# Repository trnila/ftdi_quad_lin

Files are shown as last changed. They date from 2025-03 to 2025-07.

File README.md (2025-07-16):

# FTDI Quad LIN

FTDI Quad-LIN is an FTDI-based board that enables communication with up to 4 LIN channels.

- 4x LIN master channels
- USB-C connector
- channel LED indication of power presence and communication activity
- power jack to power selected transceiver and its network

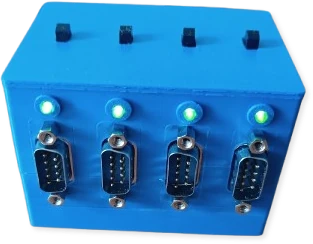
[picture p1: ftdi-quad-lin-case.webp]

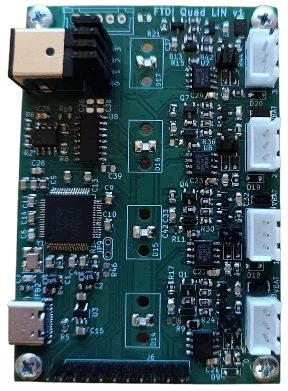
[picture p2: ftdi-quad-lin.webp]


## Getting started
Install dkms driver for sllin module:
```
$ ./install_driver.sh
```

Then run following commands to:
- write given serial number into the device
- install a udev rule to start `ldattach@.service` on USB plug-in
- copy `sllin.network` file to automatically bringup `slcan` interface up

```
$ sudo apt install ftdi-eeprom
$ ./setup.sh some_serial_number
```

## Tests

Connect all channels to 2x PCAN-USB Pro, then install peak driver:
```sh
$ wget https://www.peak-system.com/quick/PLIN-Linux-Driver -O plin_linux_driver.tar.gz
$ tar -xf plin_linux_driver.tar.gz
$ cd peak-lin-driver-1.4.0
$ make
$ sudo make install
```

Then test all channels as masters by sending frames to the connected PCAN-USB device:
```
$ uv run pytest
```

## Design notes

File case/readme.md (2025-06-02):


# Case
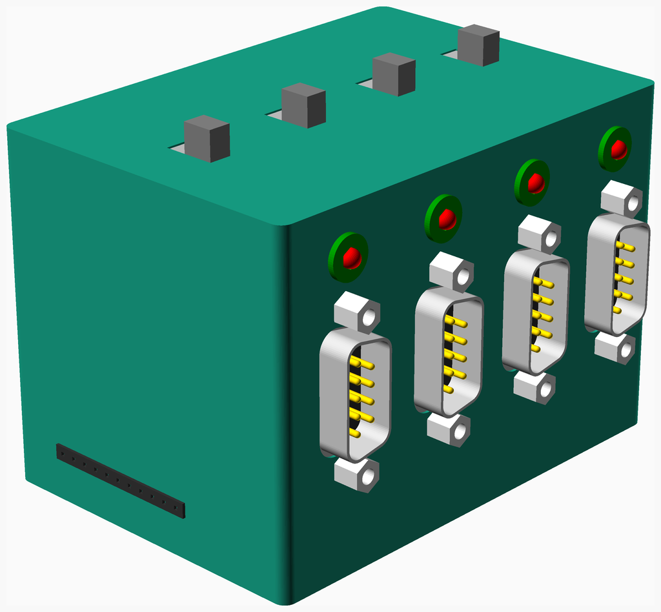
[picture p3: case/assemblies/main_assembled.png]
Main Assembly


<span></span>

---
## Table of Contents
1. [Parts list](#Parts_list)
1. [Ftdi Quad Lin Box Base Assembly](#ftdi_quad_lin_box_base_assembly)
1. [Led Activity Assembly](#led_activity_assembly)
1. [Ftdi Quad Lin Box Assembly](#ftdi_quad_lin_box_assembly)
1. [Main Assembly](#main_assembly)

<span></span>
[Top](#TOP)

---

## Parts list
| <span style="writing-mode: vertical-rl; text-orientation: mixed;">Ftdi&nbsp;Quad&nbsp;Lin&nbsp;Box&nbsp;Base</span> | <span style="writing-mode: vertical-rl; text-orientation: mixed;">4 x Led&nbsp;Activity</span> | <span style="writing-mode: vertical-rl; text-orientation: mixed;">Ftdi&nbsp;Quad&nbsp;Lin&nbsp;Box</span> | <span style="writing-mode: vertical-rl; text-orientation: mixed;">Main</span> | <span style="writing-mode: vertical-rl; text-orientation: mixed;">TOTALS</span> |  |
|---:|---:|---:|---:|---:|:---|
|  |  |  |  | | **Vitamins** |
| &nbsp;&nbsp;.&nbsp; | &nbsp;&nbsp;.&nbsp; | &nbsp;&nbsp;4&nbsp; | &nbsp;&nbsp;.&nbsp; |  &nbsp;&nbsp;4&nbsp; | &nbsp;&nbsp; D-type 9 way  plug |
| &nbsp;&nbsp;.&nbsp; | &nbsp;&nbsp;.&nbsp; | &nbsp;&nbsp;8&nbsp; | &nbsp;&nbsp;.&nbsp; |  &nbsp;&nbsp;8&nbsp; | &nbsp;&nbsp; D-type connector pillar |
| &nbsp;&nbsp;.&nbsp; | &nbsp;&nbsp;.&nbsp; | &nbsp;&nbsp;.&nbsp; | &nbsp;&nbsp;4&nbsp; |  &nbsp;&nbsp;4&nbsp; | &nbsp;&nbsp; Heatfit insert M3 x 3mm |
| &nbsp;&nbsp;4&nbsp; | &nbsp;&nbsp;.&nbsp; | &nbsp;&nbsp;.&nbsp; | &nbsp;&nbsp;.&nbsp; |  &nbsp;&nbsp;4&nbsp; | &nbsp;&nbsp; JST XH connector 3 way |
| &nbsp;&nbsp;1&nbsp; | &nbsp;&nbsp;.&nbsp; | &nbsp;&nbsp;.&nbsp; | &nbsp;&nbsp;.&nbsp; |  &nbsp;&nbsp;1&nbsp; | &nbsp;&nbsp; JST XH connector 5 way |
| &nbsp;&nbsp;.&nbsp; | &nbsp;&nbsp;4&nbsp; | &nbsp;&nbsp;.&nbsp; | &nbsp;&nbsp;.&nbsp; |  &nbsp;&nbsp;4&nbsp; | &nbsp;&nbsp; LED 3 mm red |
| &nbsp;&nbsp;.&nbsp; | &nbsp;&nbsp;.&nbsp; | &nbsp;&nbsp;8&nbsp; | &nbsp;&nbsp;.&nbsp; |  &nbsp;&nbsp;8&nbsp; | &nbsp;&nbsp; Nut M2 x 1.6mm  |
| &nbsp;&nbsp;1&nbsp; | &nbsp;&nbsp;.&nbsp; | &nbsp;&nbsp;.&nbsp; | &nbsp;&nbsp;.&nbsp; |  &nbsp;&nbsp;1&nbsp; | &nbsp;&nbsp; Pin socket 11 x 1 right_angle |
| &nbsp;&nbsp;.&nbsp; | &nbsp;&nbsp;.&nbsp; | &nbsp;&nbsp;.&nbsp; | &nbsp;&nbsp;4&nbsp; |  &nbsp;&nbsp;4&nbsp; | &nbsp;&nbsp; Screw M3 pan x  6mm |
| &nbsp;&nbsp;.&nbsp; | &nbsp;&nbsp;.&nbsp; | &nbsp;&nbsp;4&nbsp; | &nbsp;&nbsp;.&nbsp; |  &nbsp;&nbsp;4&nbsp; | &nbsp;&nbsp; SlideSwitch |
| &nbsp;&nbsp;.&nbsp; | &nbsp;&nbsp;.&nbsp; | &nbsp;&nbsp;.&nbsp; | &nbsp;&nbsp;4&nbsp; |  &nbsp;&nbsp;4&nbsp; | &nbsp;&nbsp; Washer  M3 x 7mm x 0.5mm |
| &nbsp;&nbsp;1&nbsp; | &nbsp;&nbsp;.&nbsp; | &nbsp;&nbsp;.&nbsp; | &nbsp;&nbsp;.&nbsp; |  &nbsp;&nbsp;1&nbsp; | &nbsp;&nbsp; ftdi quad lin |
| &nbsp;&nbsp;7&nbsp; | &nbsp;&nbsp;4&nbsp; | &nbsp;&nbsp;24&nbsp; | &nbsp;&nbsp;12&nbsp; | &nbsp;&nbsp;47&nbsp; | &nbsp;&nbsp;Total vitamins count |
|  |  |  |  | | **3D printed parts** |
| &nbsp;&nbsp;.&nbsp; | &nbsp;&nbsp;4&nbsp; | &nbsp;&nbsp;.&nbsp; | &nbsp;&nbsp;.&nbsp; |  &nbsp;&nbsp;4&nbsp; | &nbsp;&nbsp;LED3mm_bezel.stl |
| &nbsp;&nbsp;.&nbsp; | &nbsp;&nbsp;.&nbsp; | &nbsp;&nbsp;4&nbsp; | &nbsp;&nbsp;.&nbsp; |  &nbsp;&nbsp;4&nbsp; | &nbsp;&nbsp;LED3mm_bezel_retainer.stl |
| &nbsp;&nbsp;.&nbsp; | &nbsp;&nbsp;.&nbsp; | &nbsp;&nbsp;1&nbsp; | &nbsp;&nbsp;.&nbsp; |  &nbsp;&nbsp;1&nbsp; | &nbsp;&nbsp;ftdi_quad_lin_box.stl |
| &nbsp;&nbsp;1&nbsp; | &nbsp;&nbsp;.&nbsp; | &nbsp;&nbsp;.&nbsp; | &nbsp;&nbsp;.&nbsp; |  &nbsp;&nbsp;1&nbsp; | &nbsp;&nbsp;ftdi_quad_lin_box_base.stl |
| &nbsp;&nbsp;1&nbsp; | &nbsp;&nbsp;4&nbsp; | &nbsp;&nbsp;5&nbsp; | &nbsp;&nbsp;.&nbsp; | &nbsp;&nbsp;10&nbsp; | &nbsp;&nbsp;Total 3D printed parts count |

<span></span>
[Top](#TOP)

---

## Ftdi Quad Lin Box Base Assembly
### Vitamins
|Qty|Description|
|---:|:---|
|4| JST XH connector 3 way|
|1| JST XH connector 5 way|
|1| Pin socket 11 x 1 right_angle|
|1| ftdi quad lin|

### 3D Printed parts

| 1 x ftdi_quad_lin_box_base.stl |
|---|
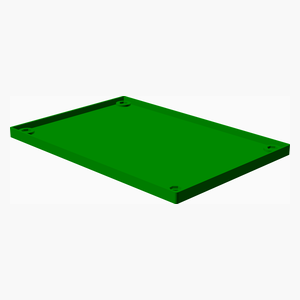
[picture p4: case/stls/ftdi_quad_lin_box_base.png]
ftdi_quad_lin_box_base.stl
|  

### Assembly instructions
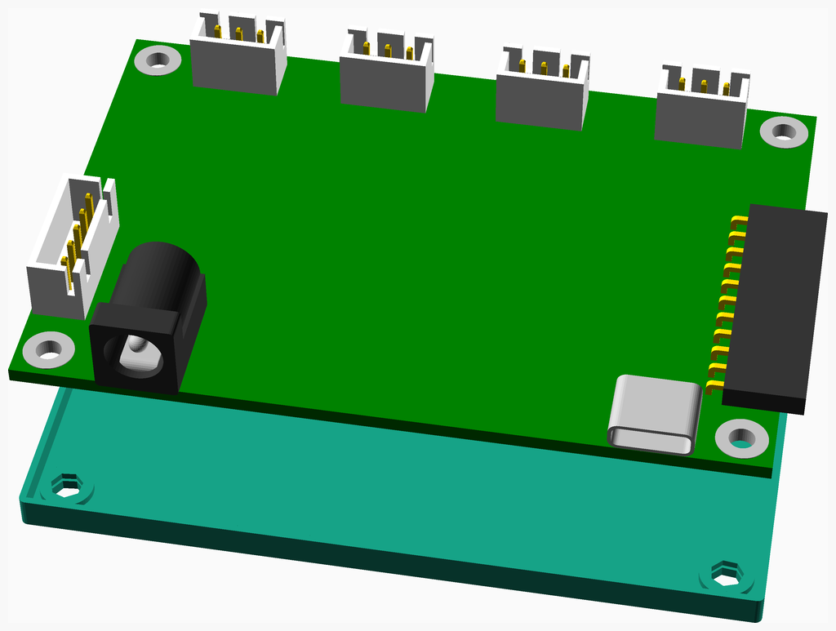
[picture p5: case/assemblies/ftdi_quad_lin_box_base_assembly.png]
ftdi_quad_lin_box_base_assembly


Place FTDI Quad LIN PCB into base part.

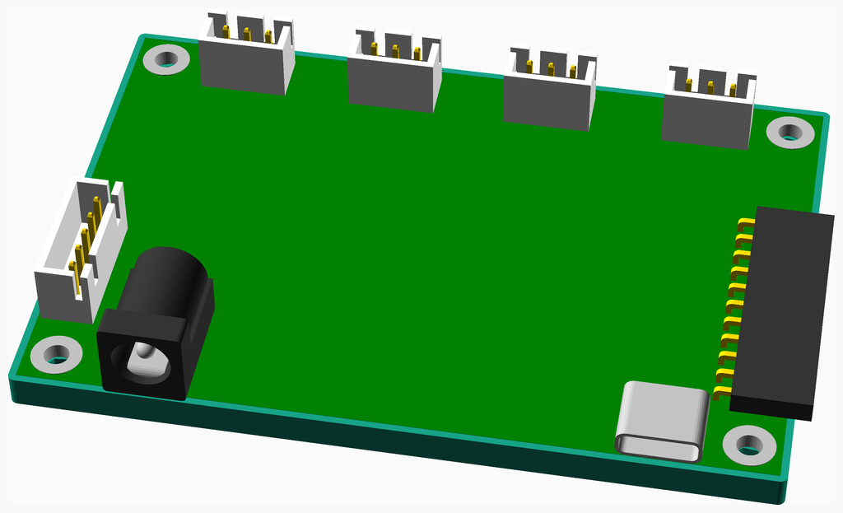
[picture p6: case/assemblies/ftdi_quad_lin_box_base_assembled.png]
ftdi_quad_lin_box_base_assembled


<span></span>
[Top](#TOP)

---

## 4 x Led Activity Assembly
### Vitamins
|Qty|Description|
|---:|:---|
|4| LED 3 mm red|

### 3D Printed parts

| 4 x LED3mm_bezel.stl |
|---|
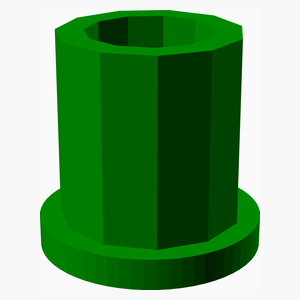
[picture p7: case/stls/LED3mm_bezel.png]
LED3mm_bezel.stl
|  

### Assembly instructions
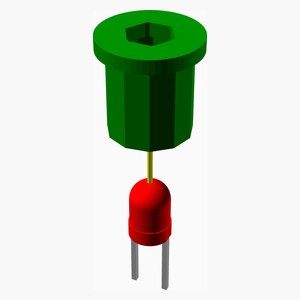
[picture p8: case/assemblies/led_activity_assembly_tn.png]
led_activity_assembly


1. Solder wire from J7 pin 5 to 3th LED anode (+)
1. Chain and solder wire to all other anodes (+)
1. solder 3th LED cathode (-) to J7 pin 4
1. solder 2th LED cathode (-) to J7 pin 3
1. solder 1th LED cathode (-) to J7 pin 2
1. solder 0th LED cathode (-) to J7 pin 1
1. Insert LEDs into the bezels

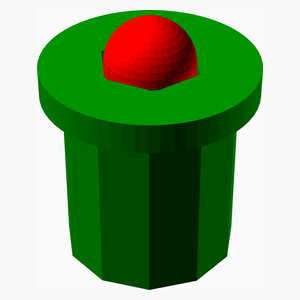
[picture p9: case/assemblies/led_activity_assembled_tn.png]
led_activity_assembled


<span></span>
[Top](#TOP)

---

## Ftdi Quad Lin Box Assembly
### Vitamins
|Qty|Description|
|---:|:---|
|4| D-type 9 way  plug|
|8| D-type connector pillar|
|8| Nut M2 x 1.6mm |
|4| SlideSwitch|

### 3D Printed parts

| 4 x LED3mm_bezel_retainer.stl | 1 x ftdi_quad_lin_box.stl |
|---|---|
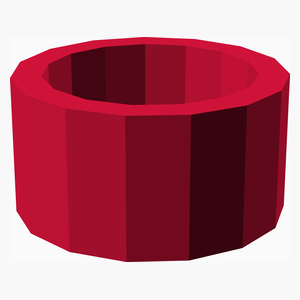
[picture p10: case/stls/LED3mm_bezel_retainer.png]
LED3mm_bezel_retainer.stl
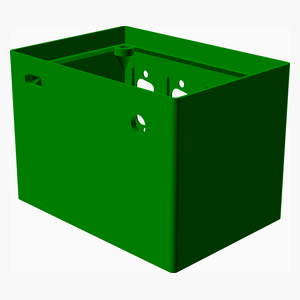
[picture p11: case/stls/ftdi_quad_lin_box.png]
ftdi_quad_lin_box.stl
|  |  

### Sub-assemblies

| 4 x led_activity_assembly |
|---|
| led_activity_assembled 

### Assembly instructions
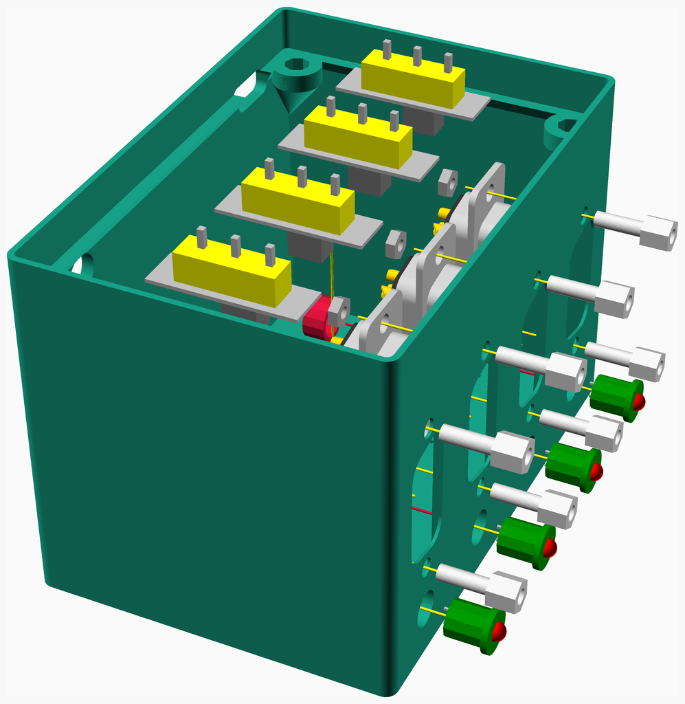
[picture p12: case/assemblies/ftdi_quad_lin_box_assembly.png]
ftdi_quad_lin_box_assembly


1. Insert 4x LED with bezel into hole and screw with retainer
2. Insert 4x slide switches and glue them inside
3. insert 4x DCONN9 connectors and secure them with pillar and nuts

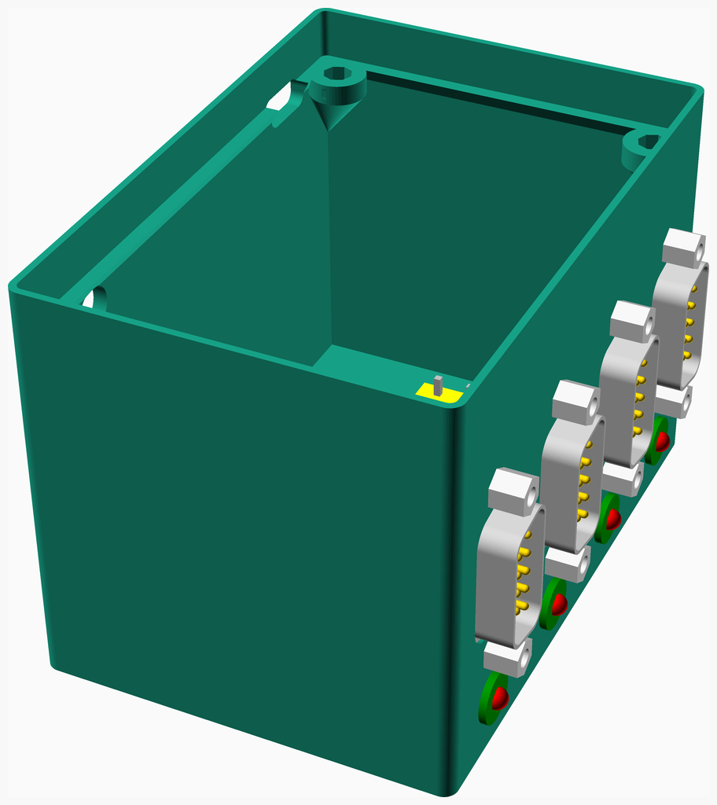
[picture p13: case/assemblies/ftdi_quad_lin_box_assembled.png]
ftdi_quad_lin_box_assembled


<span></span>
[Top](#TOP)

---

## Main Assembly
### Vitamins
|Qty|Description|
|---:|:---|
|4| Heatfit insert M3 x 3mm|
|4| Screw M3 pan x  6mm|
|4| Washer  M3 x 7mm x 0.5mm|

### Sub-assemblies

| 1 x ftdi_quad_lin_box_assembly | 1 x ftdi_quad_lin_box_base_assembly |
|---|---|
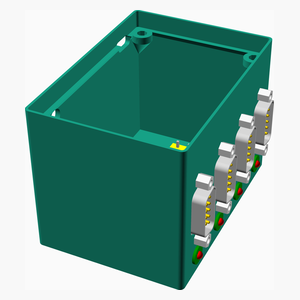
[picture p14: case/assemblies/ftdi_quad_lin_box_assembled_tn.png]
ftdi_quad_lin_box_assembled
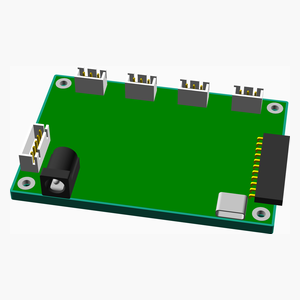
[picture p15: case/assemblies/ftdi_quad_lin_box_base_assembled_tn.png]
ftdi_quad_lin_box_base_assembled
|  |  

### Assembly instructions
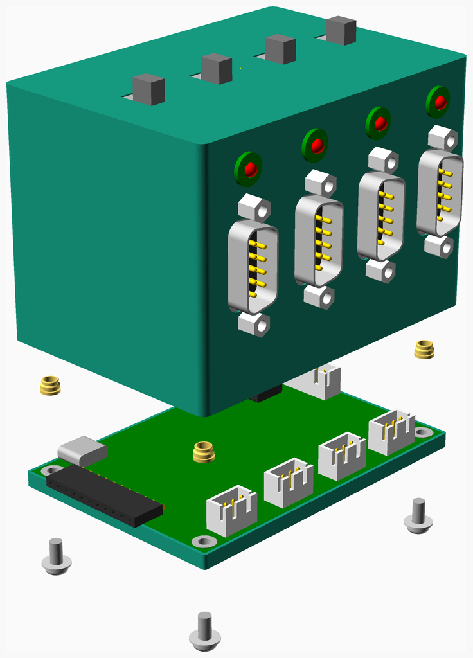
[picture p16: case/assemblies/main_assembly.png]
main_assembly


1. Place 4x heated inserts
1. Connect LEDs wire into J7
1. Connect LIN 0 power switch to JP5
1. Connect LIN 1 power switch to JP6 
1. Connect LIN 2 power switch to JP7 
1. Connect LIN 3 power switch to JP8 
1. Connect LIN 1 CONN9 to J2
1. Connect LIN 2 CONN9 to J3
1. Connect LIN 3 CONN9 to J4
1. Connect LIN 4 CONN9 to J5
1. Screw base into the box with 4x M3 screws
1. Screw the base into the box

main_assembled

<span></span>
[Top](#TOP)

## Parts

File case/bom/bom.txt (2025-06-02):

Vitamins:
    F      
    t      
    d      
    i      
           
 F  q      
 t  u      
 d  a      
 i  d      
           
 q  l  L   
 u  i  e   
 a  n  d   
 d         
    b  a   
 l  o  c   
 i  x  t   
 n     i   
    b  v  M
 b  a  i  a
 o  s  t  i
 x  e  y  n
 8|  |  |  |  8 D-type connector pillar
 4|  |  |  |  4 D-type 9 way  plug
  |  |  | 4|  4 Heatfit insert M3 x 3mm
  | 4|  |  |  4 JST XH connector 3 way
  | 1|  |  |  1 JST XH connector 5 way
  |  | 4|  |  4 LED 3 mm red
 8|  |  |  |  8 Nut M2 x 1.6mm 
  | 1|  |  |  1 ftdi quad lin
  | 1|  |  |  1 Pin socket 11 x 1 right_angle
  |  |  | 4|  4 Screw M3 pan x  6mm
 4|  |  |  |  4 SlideSwitch
  |  |  | 4|  4 Washer  M3 x 7mm x 0.5mm

Printed:
  |  | 4|  |  4 LED3mm_bezel.stl
 4|  |  |  |  4 LED3mm_bezel_retainer.stl
 1|  |  |  |  1 ftdi_quad_lin_box.stl
  | 1|  |  |  1 ftdi_quad_lin_box_base.stl

Assemblies:
  1 ftdi_quad_lin_box_assembly
  1 ftdi_quad_lin_box_base_assembly
  4 led_activity_assemblies
  1 main_assembly

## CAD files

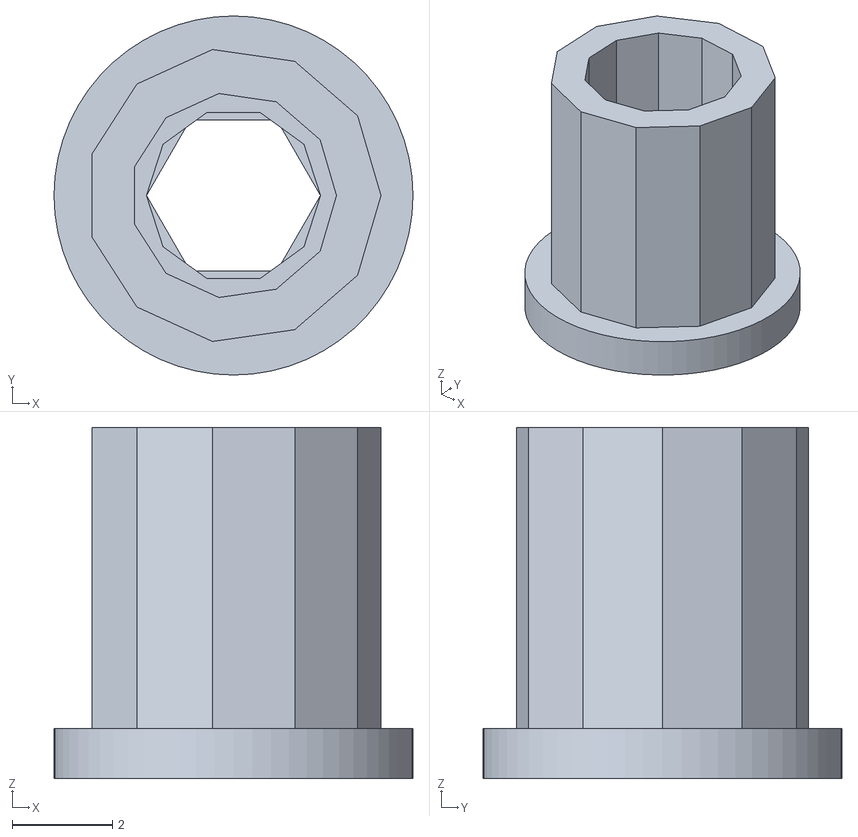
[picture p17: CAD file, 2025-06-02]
case/stls/LED3mm_bezel.stl
7.15 x 7.15 x 7.00

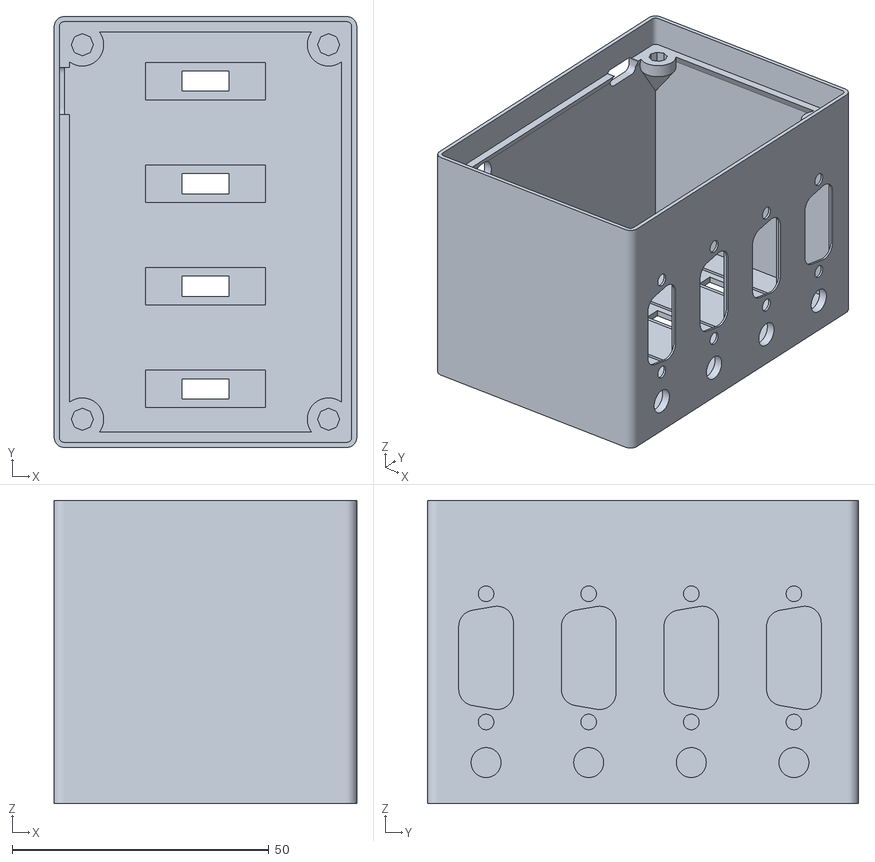
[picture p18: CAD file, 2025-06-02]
case/stls/ftdi_quad_lin_box.stl
59.0 x 84.0 x 59.1

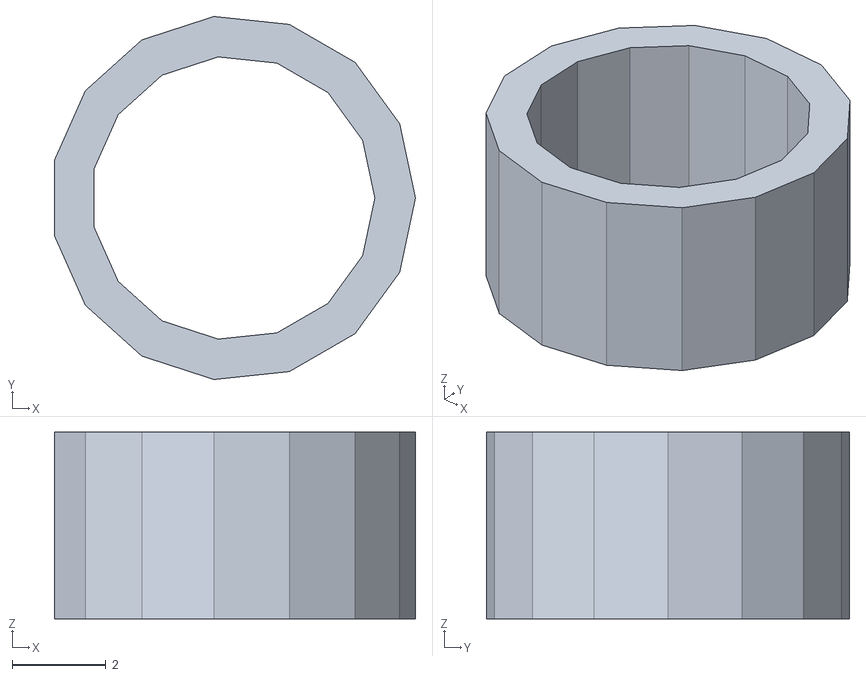
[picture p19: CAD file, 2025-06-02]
case/stls/LED3mm_bezel_retainer.stl
7.72 x 7.77 x 4.00

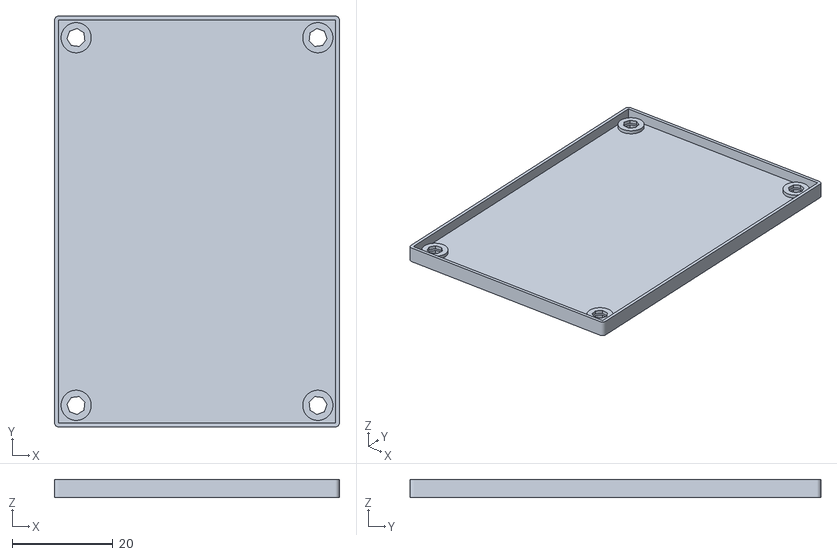
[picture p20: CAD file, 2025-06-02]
case/stls/ftdi_quad_lin_box_base.stl
56.6 x 81.6 x 3.60

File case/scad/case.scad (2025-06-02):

include <NopSCADlib/lib.scad> 
include <NopSCADlib/core.scad>
include <NopSCADlib/vitamins/d_connectors.scad>
include <NopSCADlib/vitamins/d_connector.scad>
include <NopSCADlib/vitamins/pcb.scad>
include <NopSCADlib/printed/printed_box.scad>
include <NopSCADlib/vitamins/d_connectors.scad>
include <NopSCADlib/vitamins/leds.scad>
include <NopSCADlib/vitamins/screws.scad>
include <NopSCADlib/printed/led_bezel.scad>

use <NopSCADlib/vitamins/pcb.scad>
use <NopSCADlib/printed/foot.scad>

$explode = 0;

w1 = 55;
w2 = 80;
h = 50;
wall = 2;

lever_w1 = 23.45;
lever_w2 = 7.3;
lever_hole_w1 = 9.15;
lever_hole_w2 = 3.95;
lever_btn_w1 = 5.40;
lever_thickness = 0.6;

insert_type = CNCKM3;
insert_w = insert_outer_d(insert_type);

led_dsub_spacing = 5;
led_top_spacing = 8;

pcb_thickness = 1.6;
pcb_spacing = 0.8;
pcb_tol = 0.06;
pcb_screw_offset = 3.45;

led_activity_bezel = led_bezel(LED3mm, height=7);


foot = Foot(d = 7, h = 5, t = 2, r = 1, screw = M3_pan_screw);
box_top_thickness = wall;
box_base_thickness = wall + pcb_thickness;
base_pos_z = h + box_top_thickness + box_base_thickness + 2 * eps;
module foot_stl() foot(foot);
ftdi_quad_lin_box = pbox(
    name = "ftdi_quad_lin_box",
    wall = wall,
    top_t = box_top_thickness,
    base_t = box_base_thickness,
    radius = 0,
    size = [w1, w2, h],
    screw = M3_pan_screw,
    short_insert = true
);

module barrel_jack(cutout = false) { //! Draw barrel power jack
    l = 13.2;
    w = 8.89;
    h = 9;
    bore_d = 6.3;
    bore_h = 5;
    bore_l = 11.8;
    pin_d = 2;
    front = 3.3;
    r = 0.5;
    contact_d = 2;
    contact_w = 4;
    inset = 1;
    if(cutout) {
        rotate([0, 90, 0])
            translate([-bore_h, 0])
                cylinder(d = bore_d + panel_clearance, h = 100);
    } else {
        color(grey(20)) rotate([0, 90, 0]) {
            linear_extrude(l, center = true) {
                difference() {
                    translate([-h / 2, 0])
                        rounded_square([h, w], r);

                    translate([-bore_h, 0])
                        circle(d = bore_d);

                    translate([-h / 2 - bore_h, 0])
                        square([h, w], center = true);

                }
            }
            translate_z(l / 2 - front)
                linear_extrude(front) {
                    difference() {
                        translate([-h / 2, 0])
                            rounded_square([h, w], r);

                        translate([-bore_h, 0])
                            circle(d = bore_d);
                    }
                }

            translate([-bore_h, 0])
                tube(or = w / 2 - 0.5, ir = bore_d / 2, h = l);

            translate([-bore_h, 0, -l / 2])
                cylinder(d = w -1, h = l - bore_l);
        }
        color("silver") {
            translate([l / 2 - inset - pin_d / 2, 0, bore_h])
                hull() {
                    sphere(pin_d / 2);

                    rotate([0, -90, 0])
                        cylinder(d = pin_d, h = bore_l - inset);
                }
            hull() {
                translate([l / 2 - inset - contact_d / 2, 0, bore_h - bore_d / 2])
                    rotate([90, 0, 0])
                        cylinder(d = contact_d, h = contact_w, center = true);

                translate([l / 2 - bore_l, 0,  bore_h - bore_d / 2 + contact_d / 4])
                    cube([eps, contact_w, eps], center = true);
            }
        }
    }
}


ftdi_quad_lin_pcb = ["ftdi_quad_lin_pcb", "ftdi quad lin",
    w1, w2, pcb_thickness, // length, width, thickness
    0,      // Corner radius
    2.75,   // Mounting hole diameter
    5.5,    // Pad around mounting hole
    "green",// Color
    true,   // True if the parts should be separate BOM items
    // hole offsets
    [ [3.45, 3.45], [3.45, -3.45], [-3.45, 3.45], [-3.45, -3.45] ],
    // components
    [
        [ 3.7,   12.49, 180, "usb_C"],
        [  6,       66, 180, "barrel_jack"],
        [  22.11,  7.5/*3.5*/,   0, "2p54socket", 11, 1, 1],
        
        [   15.9, 76.3,   0, "jst_xh", 5],
        [   51.2, 12.9,  90, "jst_xh", 3],
        [   51.2, 31.1,  90, "jst_xh", 3],
        [   51.2, 49.1,  90, "jst_xh", 3],
        [   51.2, 66.5,  90, "jst_xh", 3],
    ],
    // accessories
    []
];

module lin_positions() {
    dcon_w = d_flange_width(DCONN9);
    for(i = [0:3]) {
        translate([0, w2/4*i - w2/2 + 3/2*dcon_w/2, 0]) {
            children();
        }
    }
}

module dsub() {
   dcon_l = d_flange_length(DCONN9);
   lin_positions() {
        translate([w1/2, 0, dcon_l/2 + led_dsub_spacing + led_top_spacing]) {
            rotate([0, 90, 0]) {
                children();
            }
        }
    }
}

module dsub_led_activity() {
    flange_length = d_flange_length(DCONN9);
    translate([flange_length/2 + led_dsub_spacing, 0, 0]) {   
        children();
    }
}

module d_flange(type) {
    cut=0;
    tolerance=0.2;
    flange_length = d_flange_length(type);
    flange_width = d_flange_width(type);
    translate([0, 0, wall/2-1.5])
    linear_extrude(wall)
    rounded_square([flange_length+tolerance, flange_width+tolerance], 2);
}


module ftdi_quad_lin_box_base_stl() stl("ftdi_quad_lin_box_base") {
    difference() {
        union() {
            pbox_base(ftdi_quad_lin_box);
        }
        
        hole_h = (pcb_thickness+pcb_spacing);
        translate([0, 0, box_base_thickness - hole_h/2])
        cube([w1+pcb_tol, w2+pcb_tol, hole_h], center=true);
    }
    
    intersection() {
        pbox_base(ftdi_quad_lin_box);
        pbox_screw_positions(ftdi_quad_lin_box) {
            translate([0, 0, pcb_thickness])
            cylinder(d=6, h=pcb_spacing);
        }
    }
}

module ftdi_quad_lin_box_stl() stl("ftdi_quad_lin_box") {
 difference() {    
        pbox(ftdi_quad_lin_box);
        
        dsub() {
            d_hole(DCONN9, h=10);
            d_flange(DCONN9);
            d_connector_holes(DCONN9) {
                rotate([0, 0, 90])
                cylinder(r=3.05/2, h=wall*10, center=true);
            }
            
            dsub_led_activity() {
                cylinder(r=led_bezel_hole_r(led_activity_bezel), h=10);
            }
        }
        
        lin_positions() {
            translate([0, 0, wall-lever_thickness/2])
            cube([lever_w1, lever_w2, lever_thickness], center=true);
            
            cube([lever_hole_w1, lever_hole_w2, 10], center=true);
        }
        
        translate([0, 0, h + box_top_thickness + box_base_thickness/2 + 2 * eps])
        vflip()
            pcb_cutouts(ftdi_quad_lin_pcb);
    }
}


module LED3mm_bezel_stl() stl("LED3mm_bezel") {
    led_bezel(led_activity_bezel);
}

module LED3mm_bezel_retainer_stl() stl("LED3mm_bezel_retainer") {
    led_bezel_retainer(led_activity_bezel);
}

//! 1. Solder wire from J7 pin 5 to 3th LED anode (+)
//! 1. Chain and solder wire to all other anodes (+)
//! 1. solder 3th LED cathode (-) to J7 pin 4
//! 1. solder 2th LED cathode (-) to J7 pin 3
//! 1. solder 1th LED cathode (-) to J7 pin 2
//! 1. solder 0th LED cathode (-) to J7 pin 1
//! 1. Insert LEDs into the bezels
module led_activity_assembly() assembly("led_activity") {
    led = led_bezel_led(led_activity_bezel);
    d = led_diameter(led);
    translate_z(led_bezel_flange_t(led_activity_bezel)) {
        vflip()
            stl_colour(pp1_colour)
                led_bezel(led_activity_bezel);

        translate_z(-led_height(led) + (is_num(d) ? d / 2 : 0))
            explode(-13)
                led(led, "red");
    }
}

//! Place FTDI Quad LIN PCB into base part.
module ftdi_quad_lin_box_base_assembly()
pose([ 45.70, 0.00, 280.00 ], [ 0.52, -11.90, 43.01 ])
assembly("ftdi_quad_lin_box_base") {
    ftdi_quad_lin_box_base_stl();
   
    explode(20) {
        translate([0, 0, pcb_thickness+pcb_spacing/2])
        pcb(ftdi_quad_lin_pcb);
    }
}

module slide_switch() {
    vitamin("slide_switch(SS-12F15): SlideSwitch");
    lever_h = 5;
    body_h = 5;
    body_w1 = 2/3*lever_w1;
    color("gray")
        translate([lever_hole_w1/2 - lever_btn_w1/2, 0, -lever_h/2])
            cube([lever_btn_w1, lever_hole_w2, lever_h], center=true);
        
        translate([0, 0, lever_thickness])
            color("silver")
            cube([lever_w1, lever_w2, lever_thickness], center=true);
        
        translate([0, 0, lever_thickness+body_h/2])
        color("yellow")
            cube([body_w1, 2/3*lever_w2, body_h], center=true);
    
        for(i = [-1, 0, 1]) {
            translate([i * body_w1/3, 0, lever_thickness+body_h])
            color("silver")
                cube([1, 1, 3]);
        }
        
}
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

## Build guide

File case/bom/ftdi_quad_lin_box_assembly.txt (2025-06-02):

ftdi_quad_lin_box_assembly:
Vitamins:
  8 D-type connector pillar
  4 D-type 9 way  plug
  8 Nut M2 x 1.6mm 
  4 SlideSwitch

Printed:
  4 LED3mm_bezel_retainer.stl
  1 ftdi_quad_lin_box.stl

Assemblies:
  4 led_activity_assemblies

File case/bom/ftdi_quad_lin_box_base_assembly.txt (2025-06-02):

ftdi_quad_lin_box_base_assembly:
Vitamins:
  4 JST XH connector 3 way
  1 JST XH connector 5 way
  1 ftdi quad lin
  1 Pin socket 11 x 1 right_angle

Printed:
  1 ftdi_quad_lin_box_base.stl

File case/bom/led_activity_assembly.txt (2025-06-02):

led_activity_assemblies:
Vitamins:
  4 LED 3 mm red

Printed:
  4 LED3mm_bezel.stl

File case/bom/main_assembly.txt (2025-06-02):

main_assembly:
Vitamins:
  4 Heatfit insert M3 x 3mm
  4 Screw M3 pan x  6mm
  4 Washer  M3 x 7mm x 0.5mm

Assemblies:
  1 ftdi_quad_lin_box_assembly
  1 ftdi_quad_lin_box_base_assembly

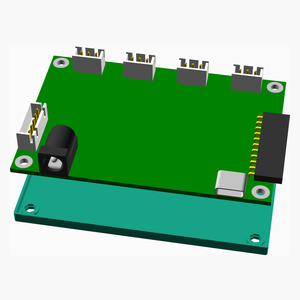
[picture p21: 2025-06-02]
case/assemblies/ftdi_quad_lin_box_base_assembly_tn.png

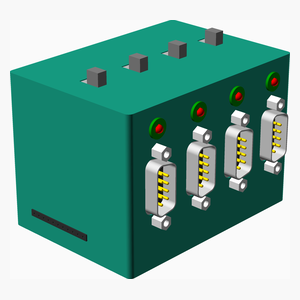
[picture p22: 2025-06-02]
case/assemblies/main_assembled_tn.png

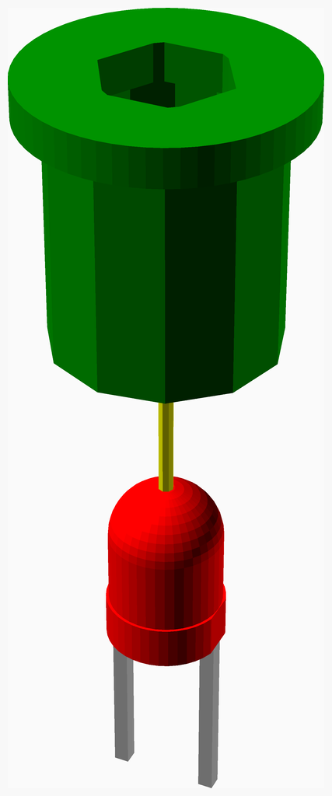
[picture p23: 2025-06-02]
case/assemblies/led_activity_assembly.png

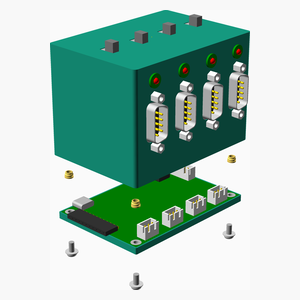
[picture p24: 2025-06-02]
case/assemblies/main_assembly_tn.png

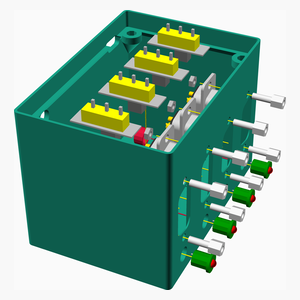
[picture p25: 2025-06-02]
case/assemblies/ftdi_quad_lin_box_assembly_tn.png

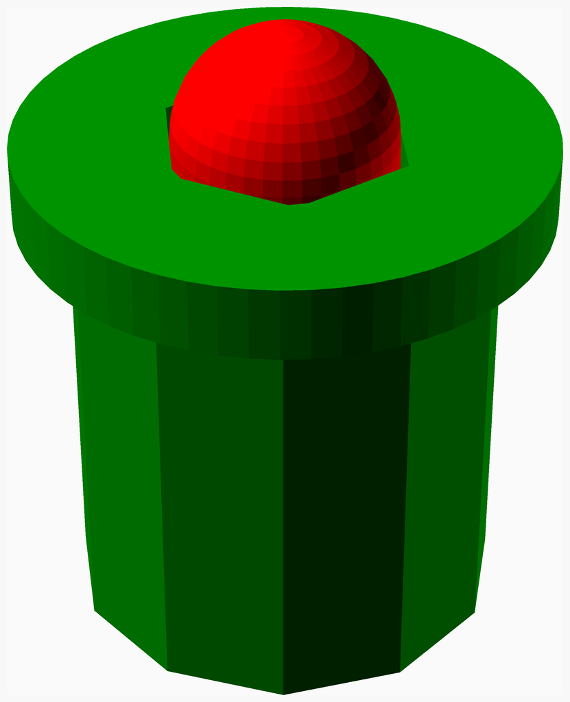
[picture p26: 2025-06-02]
case/assemblies/led_activity_assembled.png

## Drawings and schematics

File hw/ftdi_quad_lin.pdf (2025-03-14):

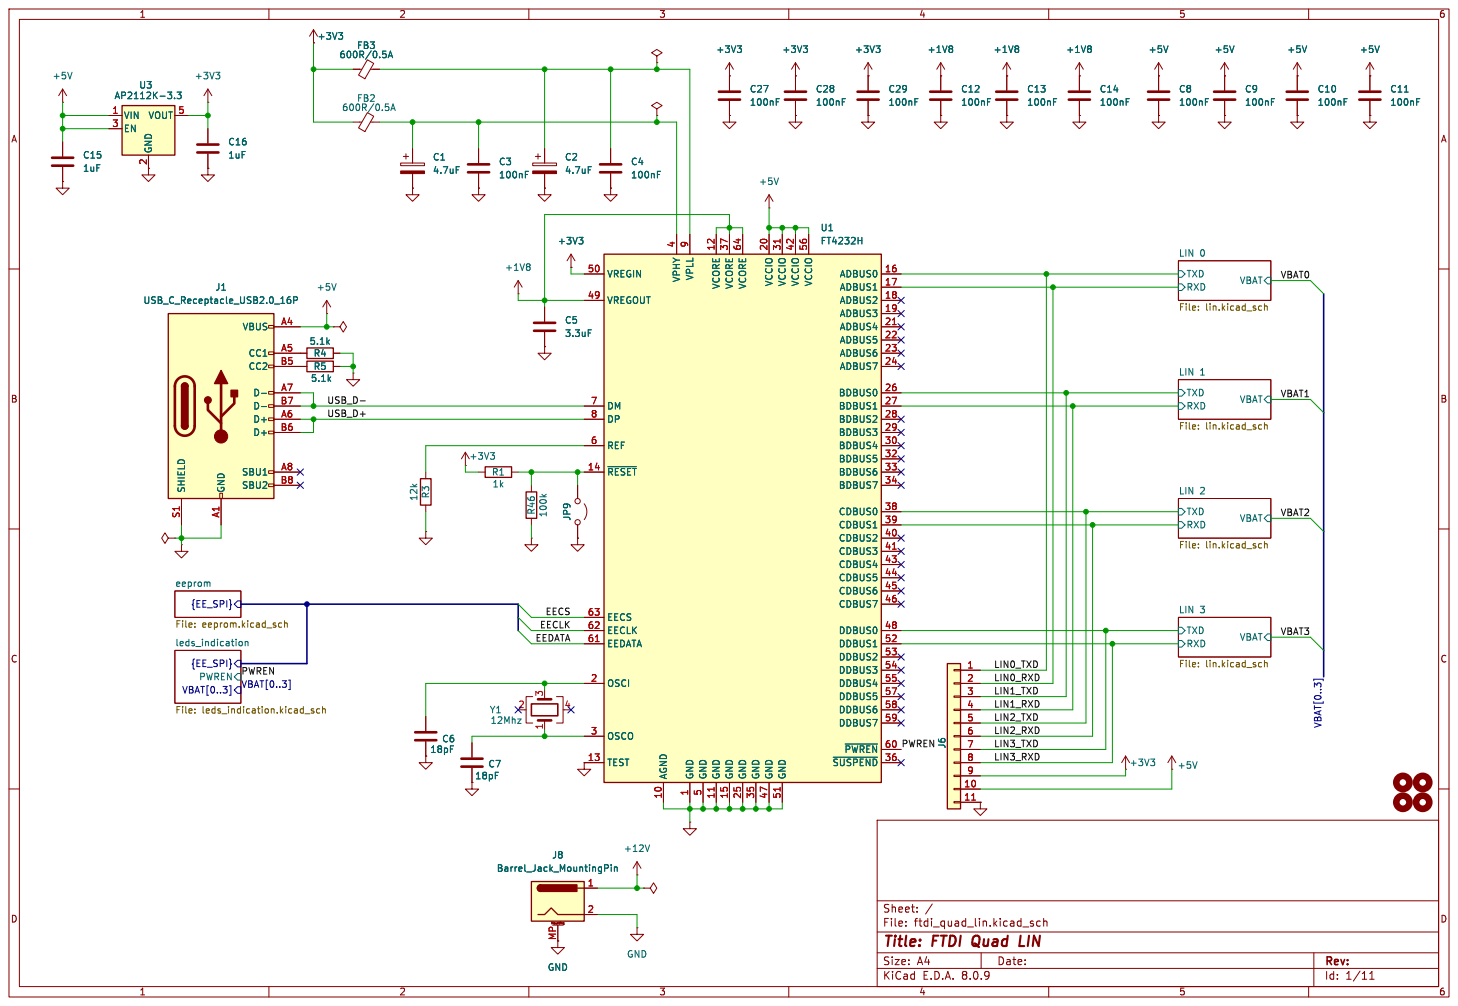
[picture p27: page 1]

LIN 0 File: lin.kicad_sch RXD

1 AGND 10 GND 11 VCORE 12 TEST 13 ~{RESET} 14 GND 15 ADBUS0 16 ADBUS1 17 ADBUS2 18 ADBUS3 19 OSCI 2 VCCIO 20 ADBUS4 21 ADBUS5 22 ADBUS6 23 ADBUS7 24 GND 25 BDBUS0 26 BDBUS1 27 BDBUS2 28 BDBUS3 29 OSCO 3 BDBUS4 30 VCCIO 31 BDBUS5 32 BDBUS6 33 BDBUS7 34 GND 35
EEDATAJP9 C5

4 CDBUS2 40 CDBUS3 41 VCCIO 42 CDBUS4 43 CDBUS5 44 CDBUS6 45 CDBUS7 46 GND 47 DDBUS0 48 VREGOUT 49 GND

5 VREGIN 50 GND 51 DDBUS1 52 DDBUS2 53 DDBUS3 54 DDBUS4 55 VCCIO 56 DDBUS5 57 DDBUS6 58 DDBUS7 59 REF 6 ~{PWREN}60 EEDATA 61 EECLK 62 EECS 63 VCORE 64 DM 7 DP 8 VPLL

VBAT2 VBAT1 VBAT0 VBAT3 VBAT[0..3]
LIN 3 File: lin.kicad_sch RXD
LIN 2 File: lin.kicad_sch RXD

LIN 1 File: lin.kicad_sch PWREN

File: ftdi_quad_lin.kicad_sch Sheet: /
Id: 1/11 Title: FTDI Quad LIN

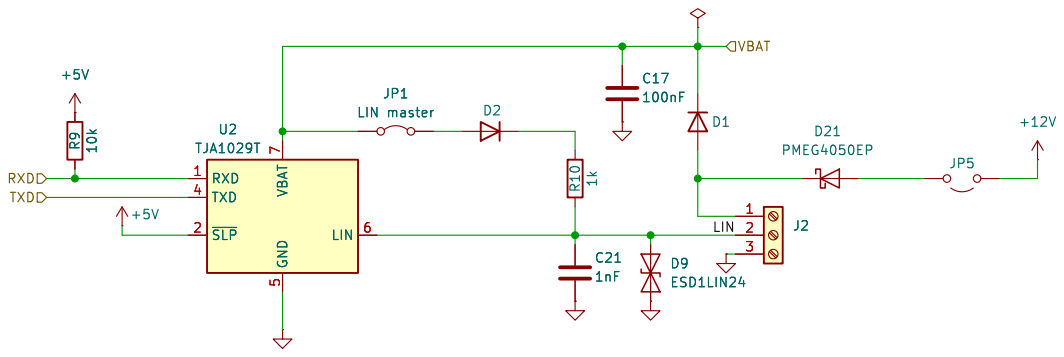
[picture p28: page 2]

Id: 2/11 Title: FTDI Quad LIN

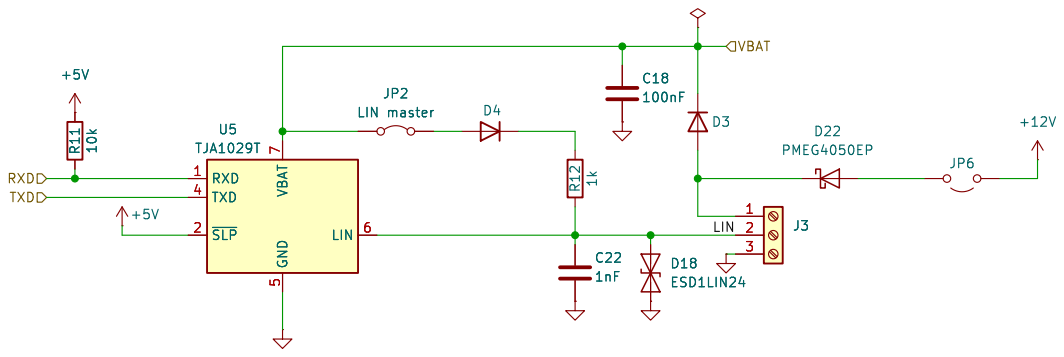
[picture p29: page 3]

Id: 3/11 Title: FTDI Quad LIN

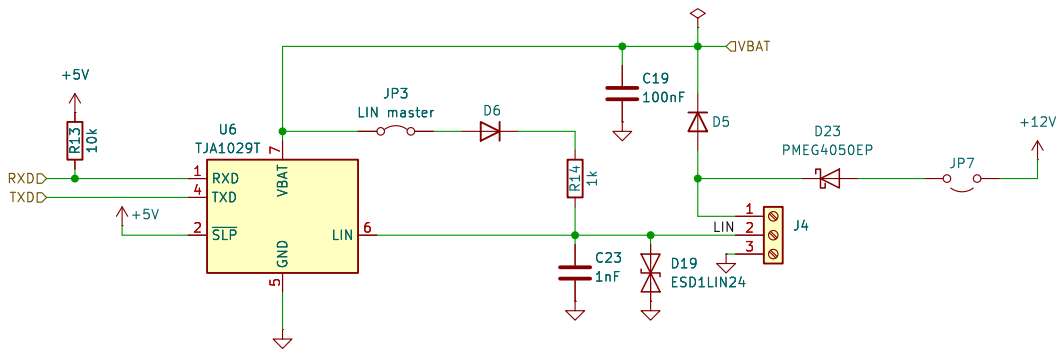
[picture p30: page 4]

Id: 4/11 Title: FTDI Quad LIN

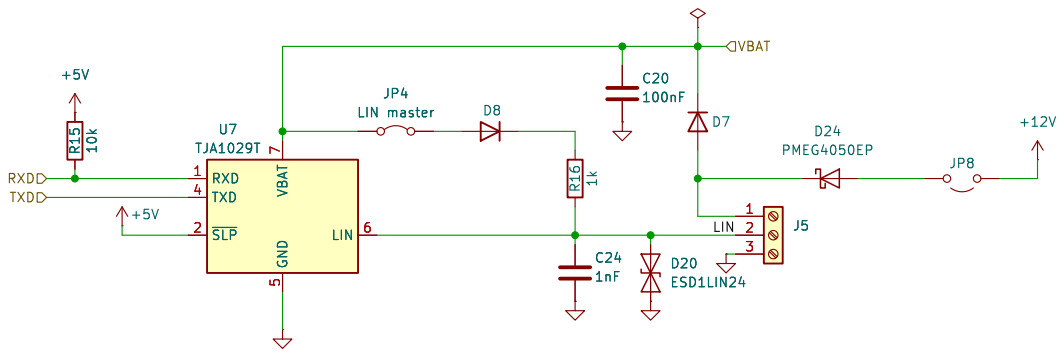
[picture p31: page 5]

Id: 5/11 Title: FTDI Quad LIN

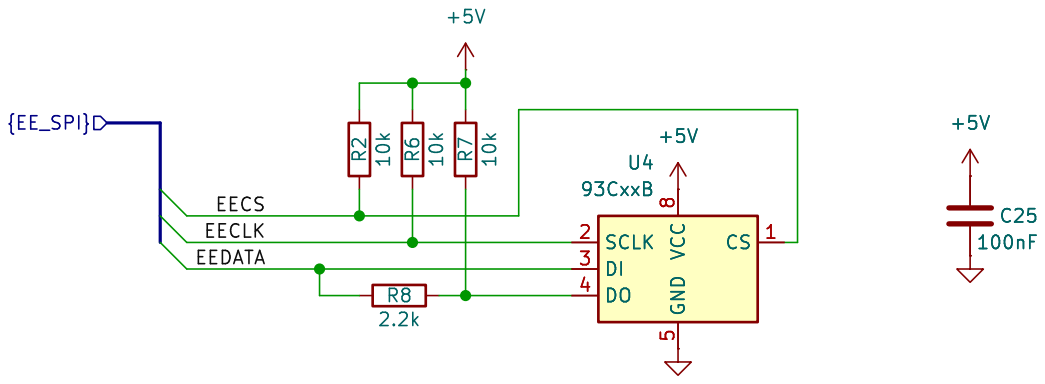
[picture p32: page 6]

Id: 6/11 Title: FTDI Quad LIN

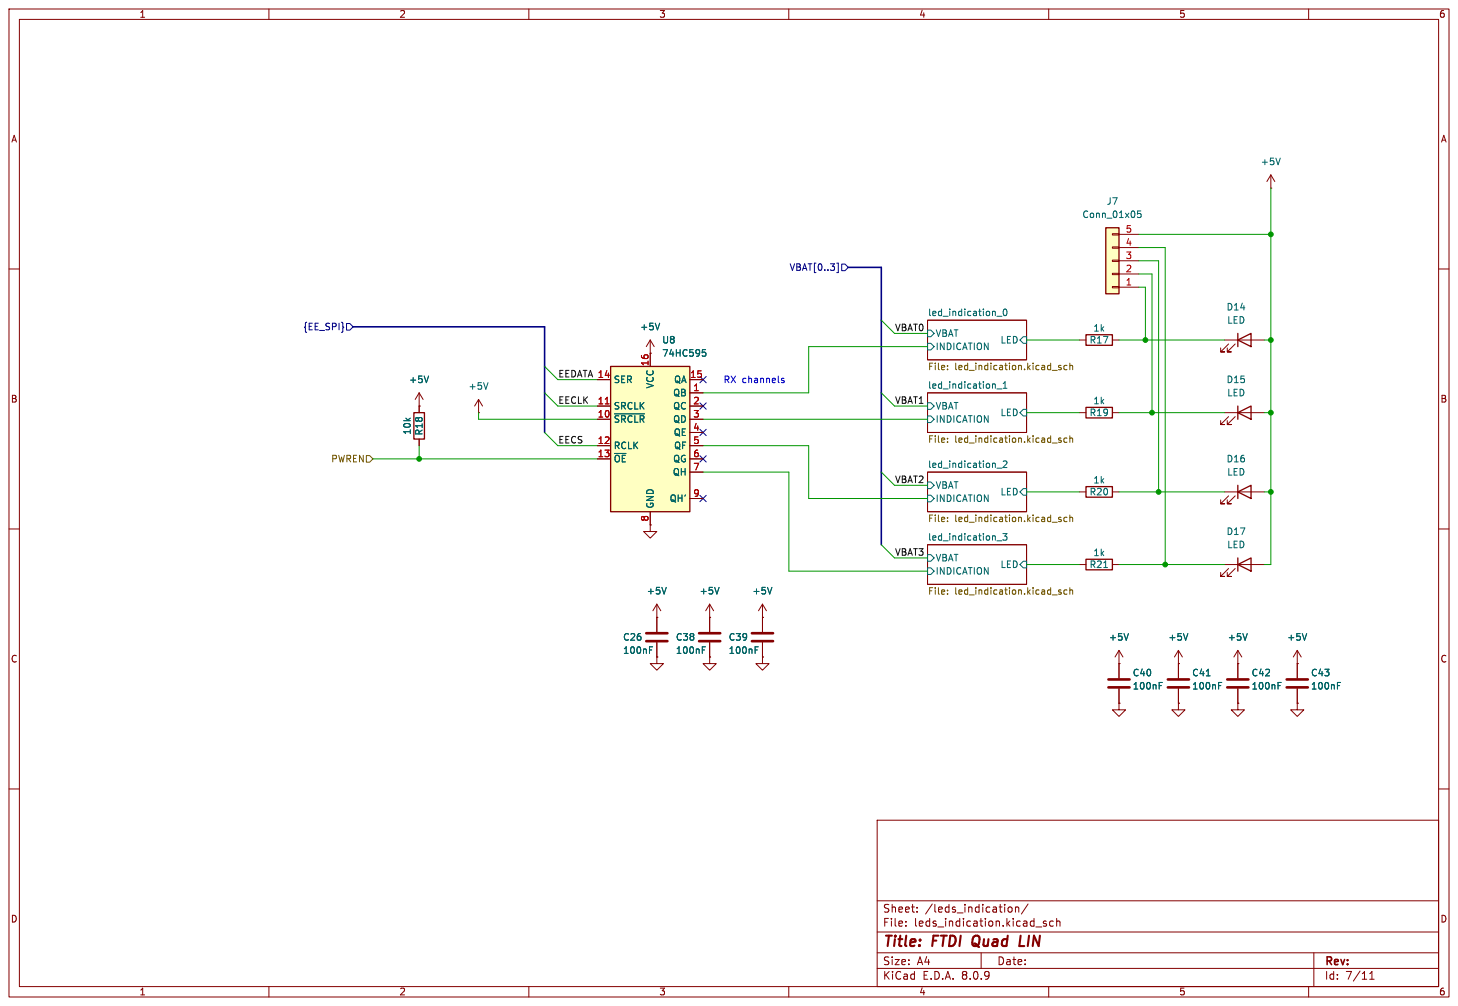
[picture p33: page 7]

File: leds_indication.kicad_sch Sheet: /leds_indication/
Id: 7/11 Title: FTDI Quad LIN

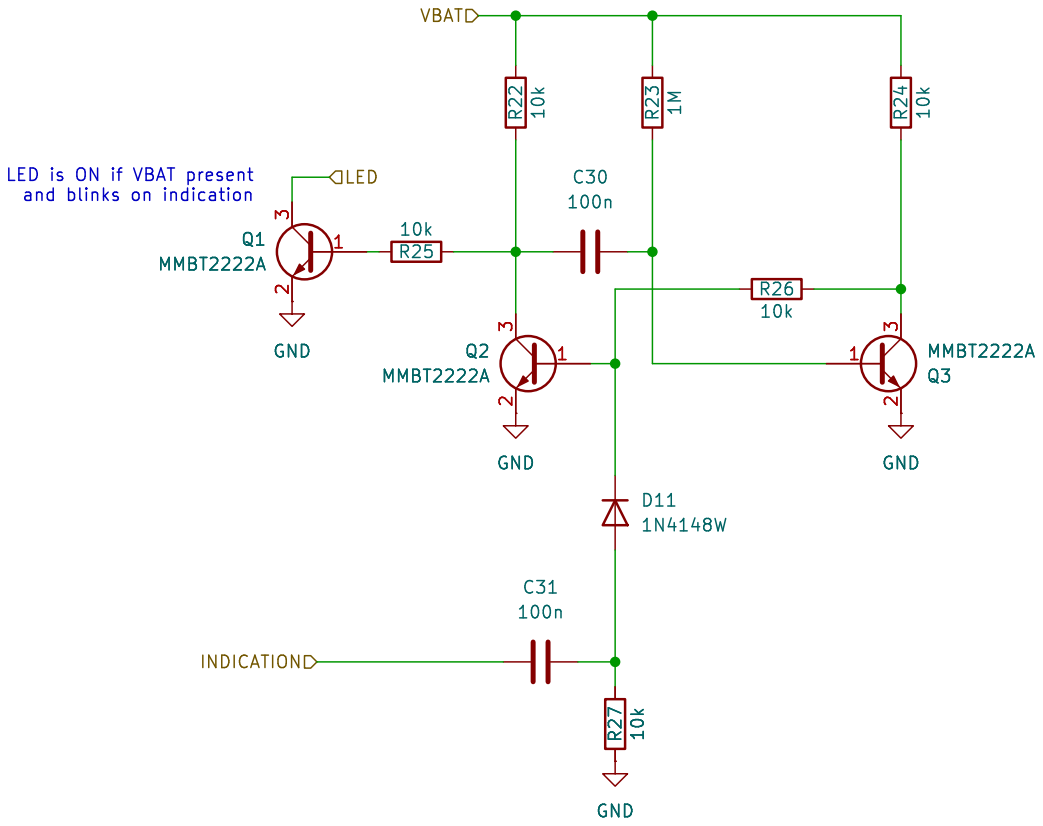
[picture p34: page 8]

Id: 8/11 Title: FTDI Quad LIN

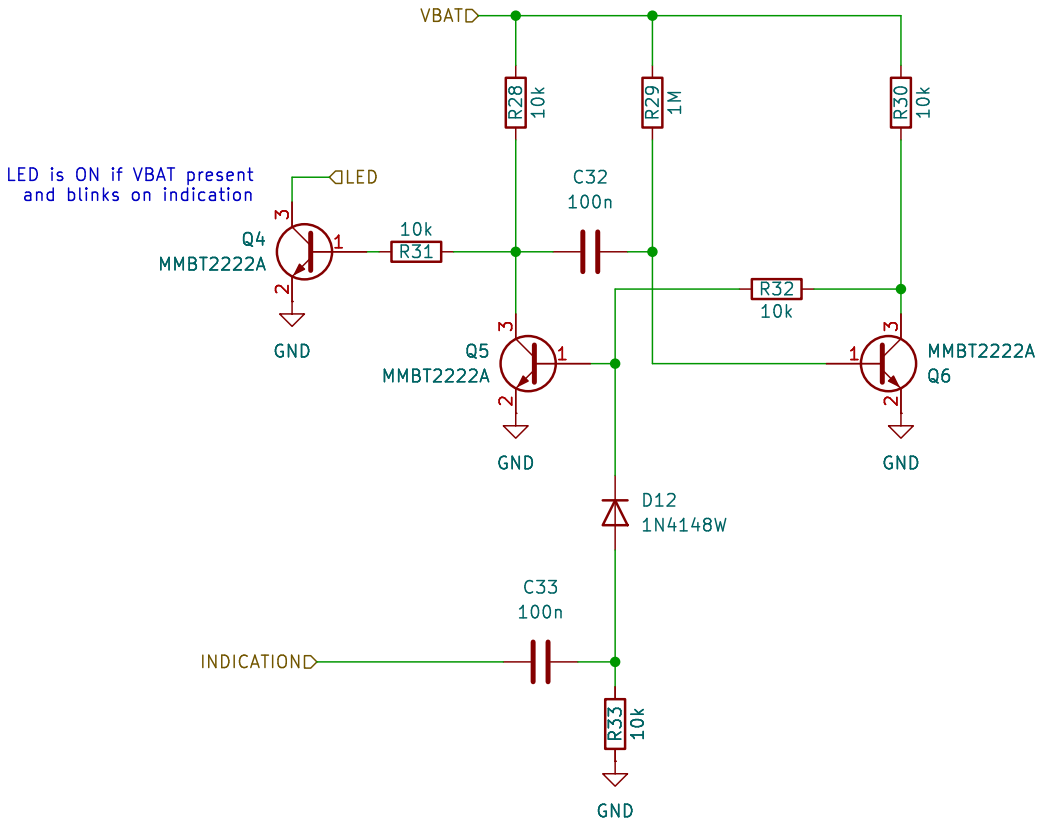
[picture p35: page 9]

Id: 9/11 Title: FTDI Quad LIN

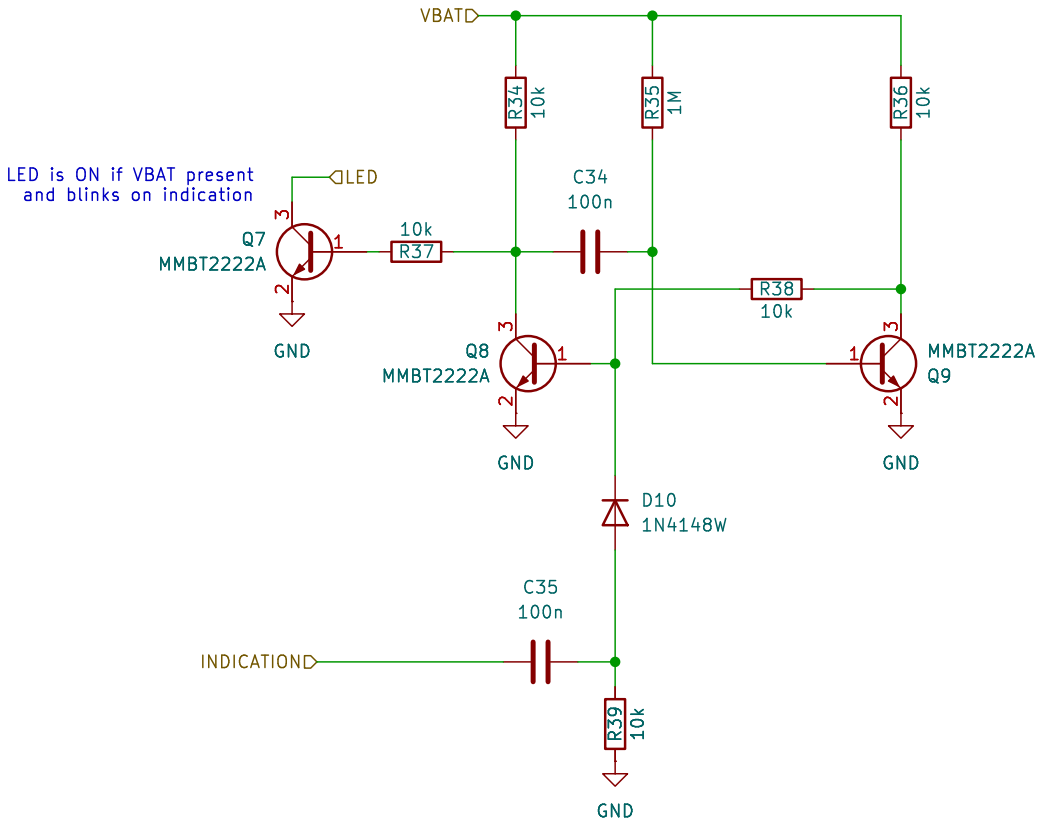
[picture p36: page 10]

Id: 10/11 Title: FTDI Quad LIN

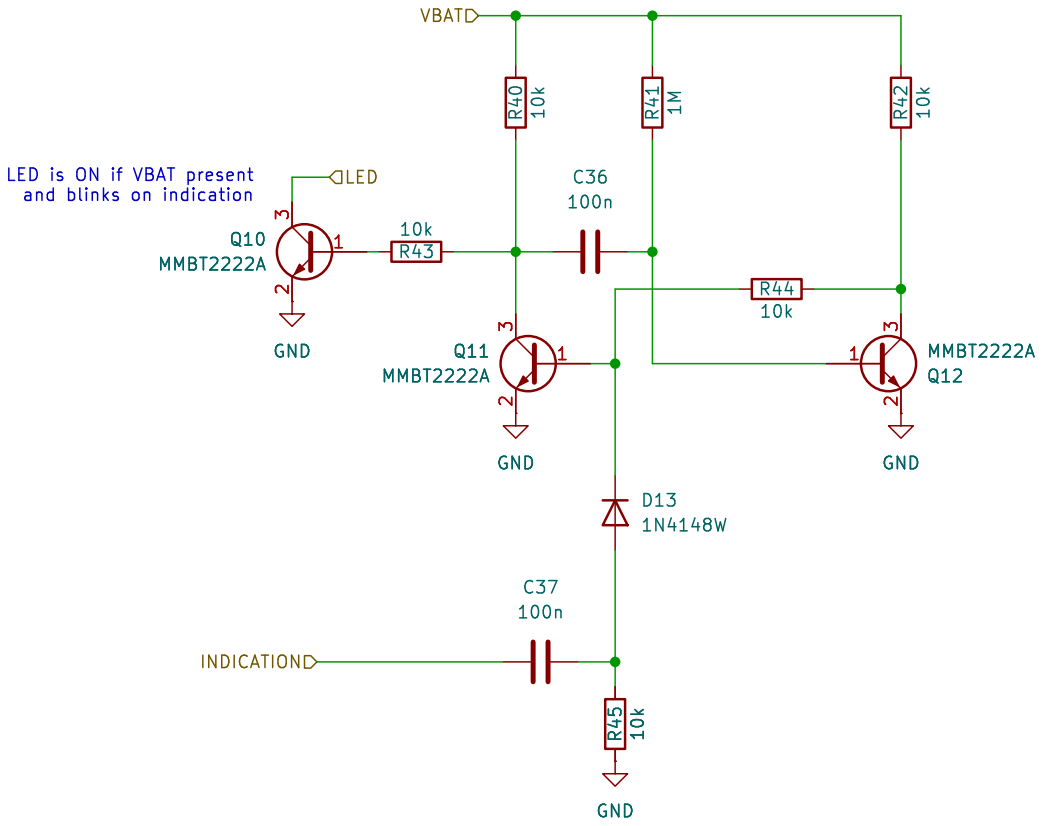
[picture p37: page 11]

Id: 11/11 Title: FTDI Quad LIN

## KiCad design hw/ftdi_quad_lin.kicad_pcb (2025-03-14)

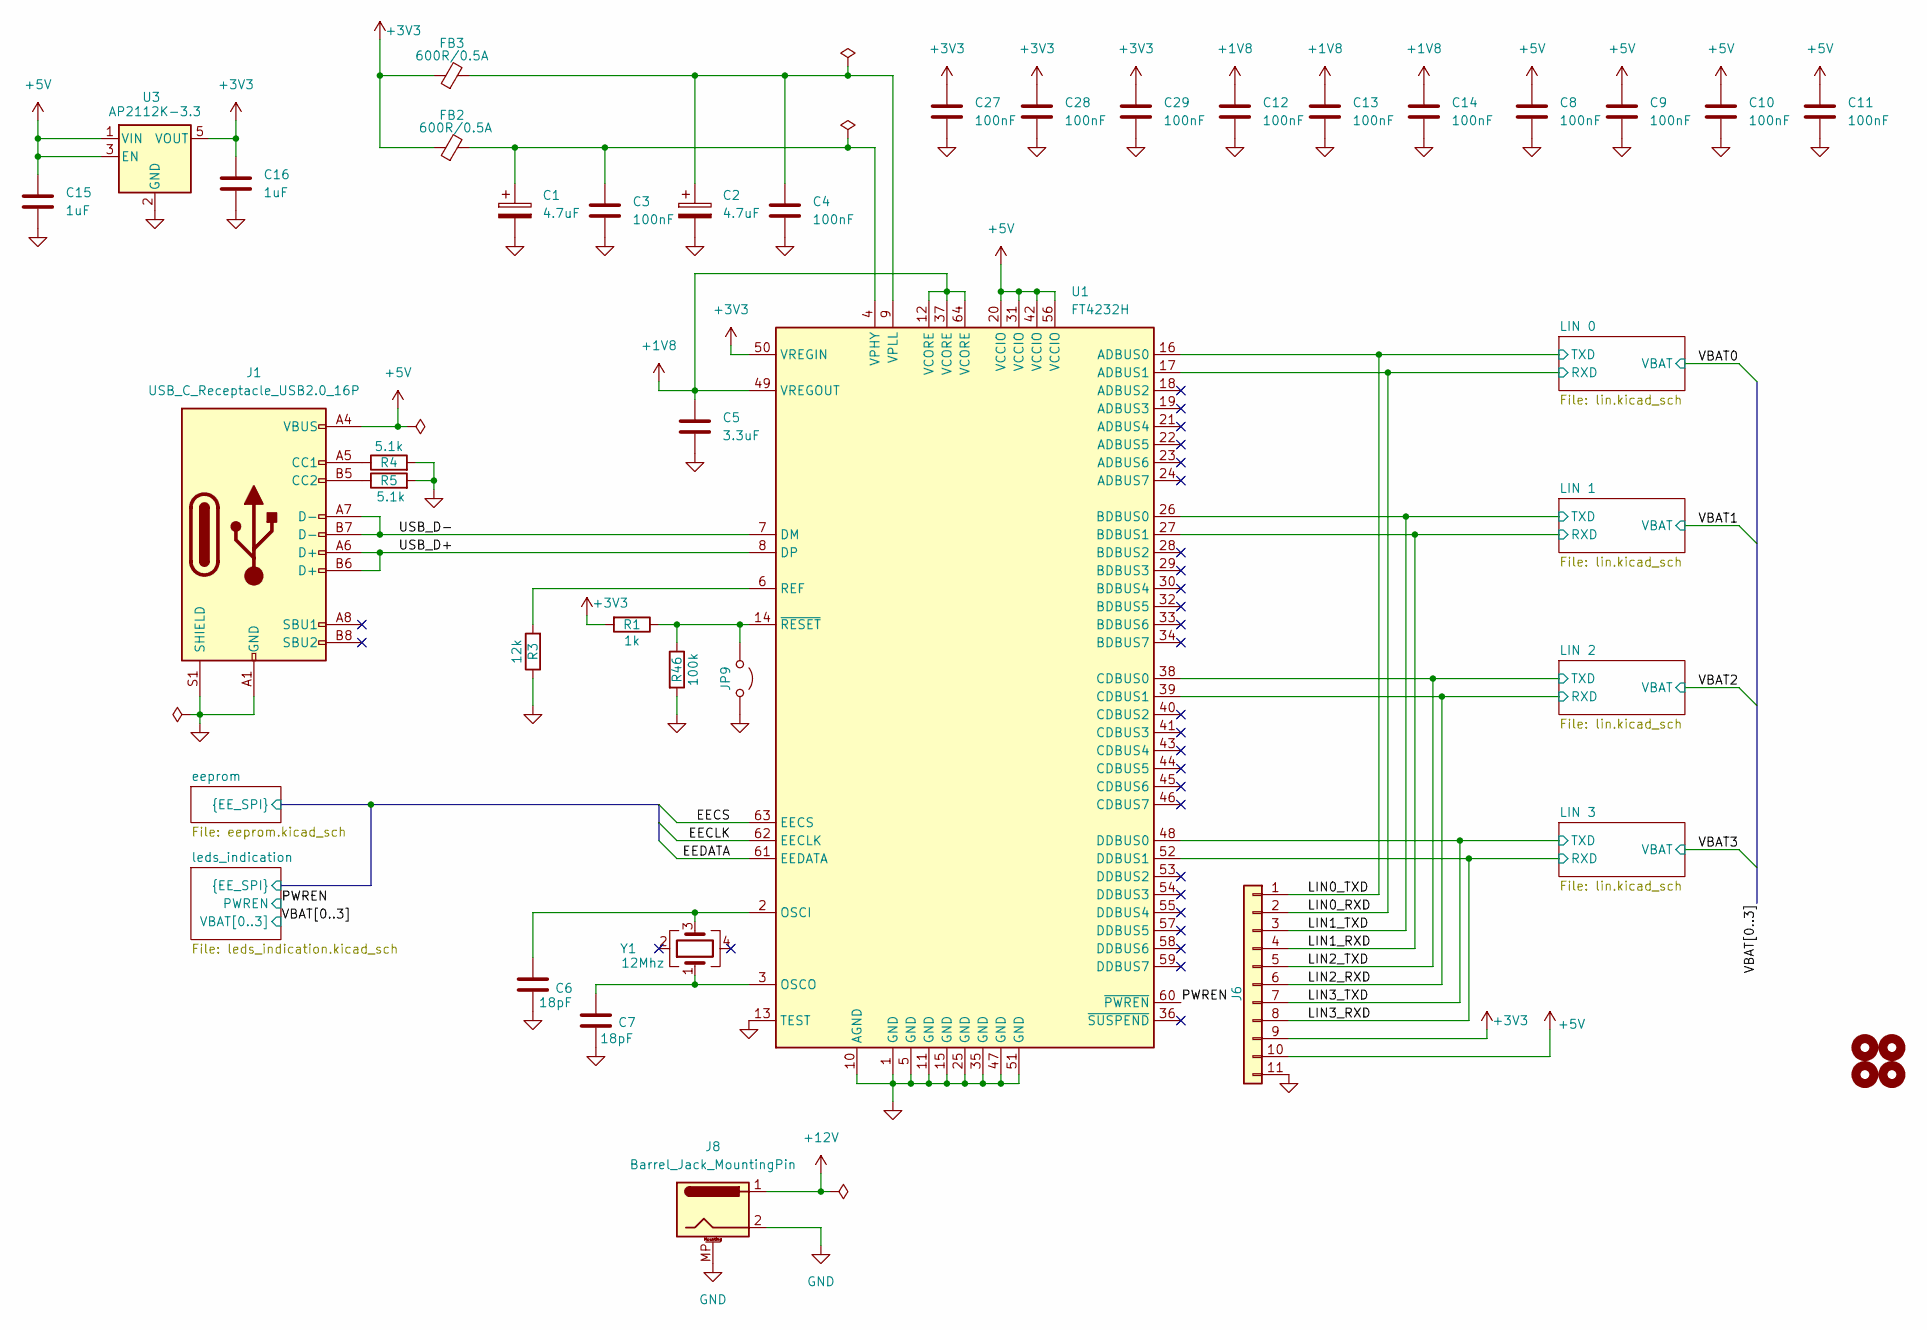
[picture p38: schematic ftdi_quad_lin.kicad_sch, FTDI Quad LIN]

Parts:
C1, C2: 4.7uF; C_1206_3216Metric_Pad1.33x1.80mm_HandSolder
C3, C4, C8, C9, C10, C11, C12, C13, C14, C27, C28, C29: 100nF; C_0805_2012Metric
C5: 3.3uF; C_0805_2012Metric
C6, C7: 18pF; C_0805_2012Metric
C15, C16: 1uF; C_0805_2012Metric
FB2, FB3: 600R/0.5A; L_0603_1608Metric_Pad1.05x0.95mm_HandSolder
H1, H2, H3, H4: MountingHole; MountingHole_3.2mm_M3
J1: USB_C_Receptacle_USB2.0_16P; USB_C_Receptacle_GCT_USB4105-xx-A_16P_TopMnt_Horizontal
J6: Conn_01x10; PinHeader_1x11_P2.54mm_Vertical
J8: Barrel_Jack_MountingPin; BarrelJack_CUI_PJ-063AH_Horizontal
JP9: Jumper_2_Open; TestPoint_2Pads_Pitch2.54mm_Drill0.8mm
R1: 1k; R_0805_2012Metric
R3: 12k; R_0805_2012Metric
R4, R5: 5.1k; R_0805_2012Metric
R46: 100k; R_0805_2012Metric
U1: FT4232H; LQFP-64_10x10mm_P0.5mm
U3: AP2112K-3.3; SOT-23-5_HandSoldering
Y1: 12Mhz; Crystal_SMD_TXC_7M-4Pin_3.2x2.5mm_HandSoldering

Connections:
+1V8: C5.1, C12.1, C13.1, C14.1, U1.12 (VCORE), U1.37 (VCORE), U1.49 (VREGOUT), U1.64 (VCORE)
+3V3: C16.1, C27.1, C28.1, C29.1, FB2.1, FB3.1, J6.9, R1.2, U1.50 (VREGIN), U3.5 (VOUT)
+5V: C8.1, C9.1, C10.1, C11.1, C15.1, J1.A4 (VBUS), J1.A9 (VBUS), J1.B4 (VBUS), J1.B9 (VBUS), J6.10, U1.20 (VCCIO), U1.31 (VCCIO), U1.42 (VCCIO), U1.56 (VCCIO), U3.1 (VIN), U3.3 (EN); also elsewhere on the board
+12V: J8.1; also elsewhere on the board
/LIN0_RXD: J6.2, U1.17 (ADBUS1); also elsewhere on the board
/LIN0_TXD: J6.1, U1.16 (ADBUS0); also elsewhere on the board
/LIN1_RXD: J6.4, U1.27 (BDBUS1); also elsewhere on the board
/LIN1_TXD: J6.3, U1.26 (BDBUS0); also elsewhere on the board
/LIN2_RXD: J6.6, U1.39 (CDBUS1); also elsewhere on the board
/LIN2_TXD: J6.5, U1.38 (CDBUS0); also elsewhere on the board
/LIN3_RXD: J6.8, U1.52 (DDBUS1); also elsewhere on the board
/LIN3_TXD: J6.7, U1.48 (DDBUS0); also elsewhere on the board
/PWREN: U1.60 (~PWREN); also elsewhere on the board
/USB_D+: J1.A6 (D+), J1.B6 (D+), U1.8 (DP)
/USB_D-: J1.A7 (D-), J1.B7 (D-), U1.7 (DM)
/eeprom/EECLK: U1.62 (EECLK); also elsewhere on the board
/eeprom/EECS: U1.63 (EECS); also elsewhere on the board
/eeprom/EEDATA: U1.61 (EEDATA); also elsewhere on the board
GND: C1.2, C2.2, C3.2, C4.2, C5.2, C6.2, C7.2, C8.2, C9.2, C10.2, C11.2, C12.2, C13.2, C14.2, C15.2, C16.2, C27.2, C28.2, C29.2, J1.A1 (GND), J1.A12 (GND), J1.B1 (GND), J1.B12 (GND), J1.S1 (SHIELD), J6.11, J8.2, J8.MP (MountPin), JP9.2 (B), R3.1, R4.2, R5.2, R46.2, U1.1 (GND), U1.5 (GND), U1.10 (AGND), U1.11 (GND), U1.13 (TEST), U1.15 (GND), U1.25 (GND), U1.35 (GND), U1.47 (GND), U1.51 (GND), U3.2 (GND); also elsewhere on the board
unnamed: J1.A5 (CC1), R4.1
unnamed: J1.B5 (CC2), R5.1
unnamed: JP9.1 (A), R1.1, R46.1, U1.14 (~RESET)
unnamed: C6.1, U1.2 (OSCI), Y1.3
unnamed: C7.1, U1.3 (OSCO), Y1.1
unnamed: R3.2, U1.6 (REF)
unnamed: C1.1, C3.1, FB2.2, U1.4 (VPHY)
unnamed: C2.1, C4.1, FB3.2, U1.9 (VPLL)

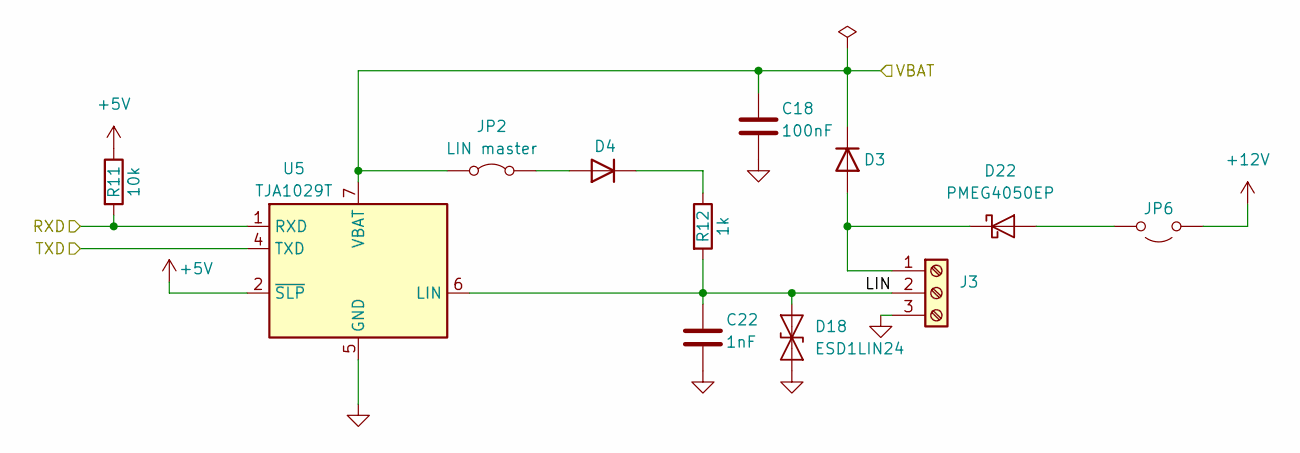
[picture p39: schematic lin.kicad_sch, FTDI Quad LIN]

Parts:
C18: 100nF; C_0805_2012Metric
C22: 1nF; C_0805_2012Metric
D3, D4: D_SOD-323_HandSoldering
D18: ESD1LIN24; D_SOD-323_HandSoldering
D22: PMEG4050EP; Nexperia_CFP3_SOD-123W
J3: Screw_Terminal_01x03; lin_connector
JP2: LIN master; TestPoint_2Pads_Pitch2.54mm_Drill0.8mm
JP6: Jumper_2_Open; TestPoint_2Pads_Pitch2.54mm_Drill0.8mm
R11: 10k; R_0805_2012Metric
R12: 1k; R_0805_2012Metric
U5: TJA1029T; SOIC-8_3.9x4.9mm_P1.27mm

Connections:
+5V: R11.1, U5.2 (~SLP); also elsewhere on the board
+12V: JP6.1 (A); also elsewhere on the board
/LIN1_RXD: R11.2, U5.1 (RXD); also elsewhere on the board
/LIN1_TXD: U5.4 (TXD); also elsewhere on the board
/LIN 1/LIN: C22.1, D18.2 (A2), J3.2, R12.2, U5.6 (LIN)
/VBAT1: C18.1, D3.1 (K), JP2.1 (A), U5.7 (VBAT); also elsewhere on the board
GND: C18.2, C22.2, D18.1 (A1), J3.3, U5.5 (GND); also elsewhere on the board
unnamed: D4.2 (A), JP2.2 (B)
unnamed: D4.1 (K), R12.1
unnamed: D22.2 (A), JP6.2 (B)
unnamed: D3.2 (A), D22.1 (K), J3.1

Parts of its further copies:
C17, C19, C20: 100nF; C_0805_2012Metric
C21, C23, C24: 1nF; C_0805_2012Metric
D1, D2, D5, D6, D7, D8: D_SOD-323_HandSoldering
D9, D19, D20: ESD1LIN24; D_SOD-323_HandSoldering
D21, D23, D24: PMEG4050EP; Nexperia_CFP3_SOD-123W
J2, J4, J5: Screw_Terminal_01x03; lin_connector
JP1, JP3, JP4: LIN master; TestPoint_2Pads_Pitch2.54mm_Drill0.8mm
JP5, JP7, JP8: Jumper_2_Open; TestPoint_2Pads_Pitch2.54mm_Drill0.8mm
R9, R13, R15: 10k; R_0805_2012Metric
R10, R14, R16: 1k; R_0805_2012Metric
U2, U6, U7: TJA1029T; SOIC-8_3.9x4.9mm_P1.27mm

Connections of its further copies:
+5V: R9.1, R13.1, R15.1, U2.2 (~SLP), U6.2 (~SLP), U7.2 (~SLP); also elsewhere on the board
+12V: JP5.1 (A), JP7.1 (A), JP8.1 (A); also elsewhere on the board
/LIN0_RXD: R9.2, U2.1 (RXD); also elsewhere on the board
/LIN0_TXD: U2.4 (TXD); also elsewhere on the board
/LIN2_RXD: R13.2, U6.1 (RXD); also elsewhere on the board
/LIN2_TXD: U6.4 (TXD); also elsewhere on the board
/LIN3_RXD: R15.2, U7.1 (RXD); also elsewhere on the board
/LIN3_TXD: U7.4 (TXD); also elsewhere on the board
/LIN 0/LIN: C21.1, D9.2 (A2), J2.2, R10.2, U2.6 (LIN)
/LIN 2/LIN: C23.1, D19.2 (A2), J4.2, R14.2, U6.6 (LIN)
/LIN 3/LIN: C24.1, D20.2 (A2), J5.2, R16.2, U7.6 (LIN)
/VBAT0: C17.1, D1.1 (K), JP1.1 (A), U2.7 (VBAT); also elsewhere on the board
/VBAT2: C19.1, D5.1 (K), JP3.1 (A), U6.7 (VBAT); also elsewhere on the board
/VBAT3: C20.1, D7.1 (K), JP4.1 (A), U7.7 (VBAT); also elsewhere on the board
GND: C17.2, C19.2, C20.2, C21.2, C23.2, C24.2, D9.1 (A1), D19.1 (A1), D20.1 (A1), J2.3, J4.3, J5.3, U2.5 (GND), U6.5 (GND), U7.5 (GND); also elsewhere on the board
unnamed: D1.2 (A), D21.1 (K), J2.1
unnamed: D2.2 (A), JP1.2 (B)
unnamed: D2.1 (K), R10.1
unnamed: D6.2 (A), JP3.2 (B)
unnamed: D6.1 (K), R14.1
unnamed: D8.2 (A), JP4.2 (B)
unnamed: D8.1 (K), R16.1
unnamed: D21.2 (A), JP5.2 (B)
unnamed: D23.2 (A), JP7.2 (B)
unnamed: D5.2 (A), D23.1 (K), J4.1
unnamed: D24.2 (A), JP8.2 (B)
unnamed: D7.2 (A), D24.1 (K), J5.1

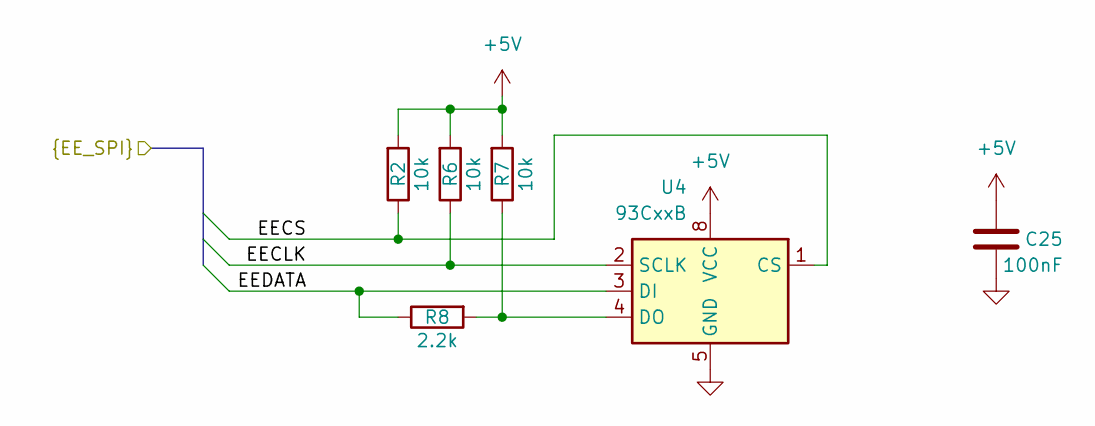
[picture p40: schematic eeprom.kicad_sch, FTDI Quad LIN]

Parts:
C25: 100nF; C_0805_2012Metric
R2, R6, R7: 10k; R_0805_2012Metric
R8: 2.2k; R_0805_2012Metric
U4: 93CxxB; SOIC-8_3.9x4.9mm_P1.27mm

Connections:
+5V: C25.1, R2.2, R6.2, R7.2, U4.8 (VCC); also elsewhere on the board
/eeprom/EECLK: R6.1, U4.2 (SCLK); also elsewhere on the board
/eeprom/EECS: R2.1, U4.1 (CS); also elsewhere on the board
/eeprom/EEDATA: R8.1, U4.3 (DI); also elsewhere on the board
GND: C25.2, U4.5 (GND); also elsewhere on the board
unnamed: R7.1, R8.2, U4.4 (DO)

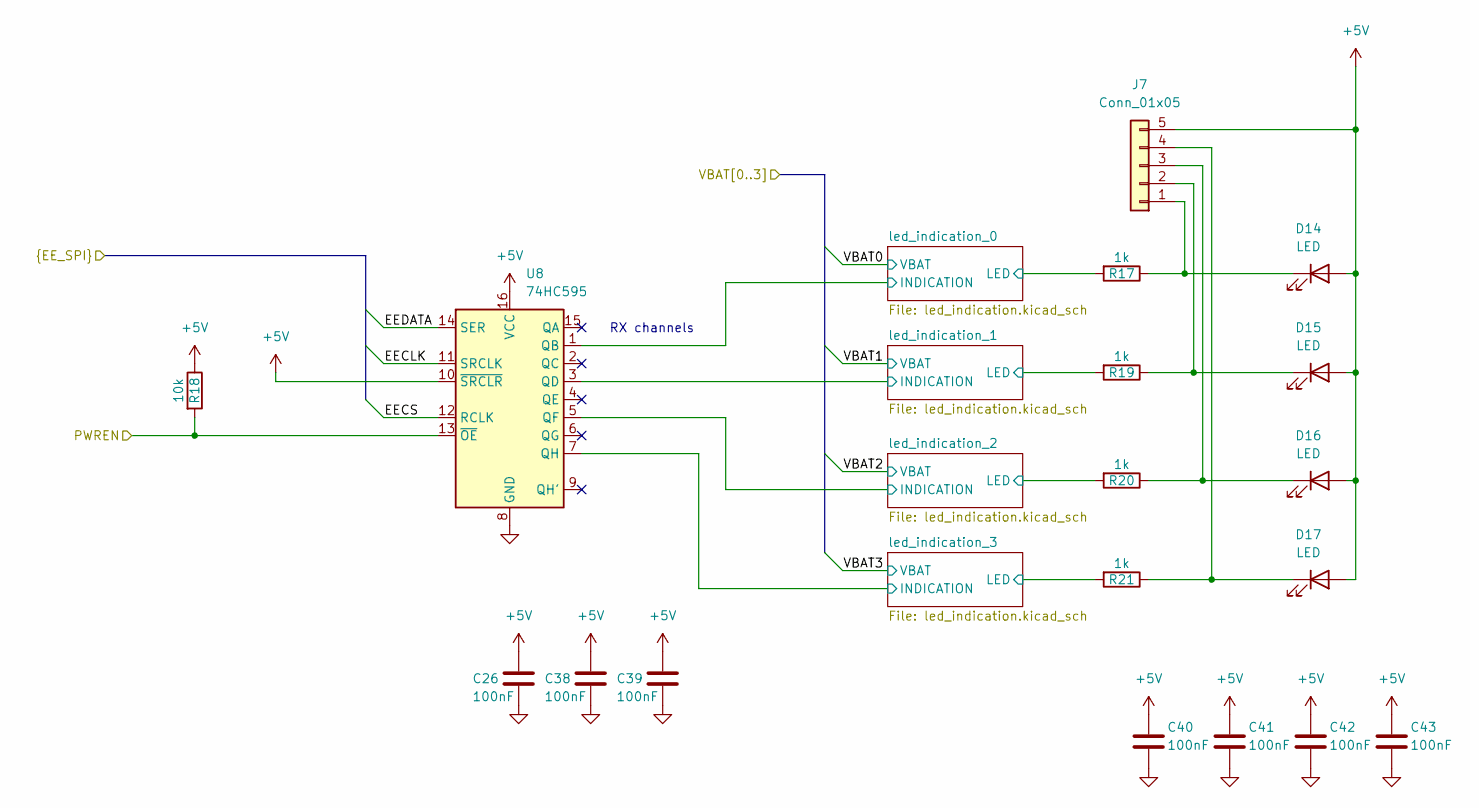
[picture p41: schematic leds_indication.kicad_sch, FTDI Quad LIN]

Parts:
C26, C38, C39, C40, C41, C42, C43: 100nF; C_0805_2012Metric
D14, D15, D16, D17: LED; 1216.1002
J7: Conn_01x05; JST_XH_B5B-XH-A_1x05_P2.50mm_Vertical
R17, R19, R20, R21: 1k; R_0805_2012Metric
R18: 10k; R_0805_2012Metric
U8: 74HC595; SOIC-16_3.9x9.9mm_P1.27mm

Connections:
+5V: C26.1, C38.1, C39.1, C40.1, C41.1, C42.1, C43.1, D14.2 (A), D15.2 (A), D16.2 (A), D17.2 (A), J7.5, R18.1, U8.10 (~SRCLR), U8.16 (VCC); also elsewhere on the board
/PWREN: R18.2, U8.13 (~OE); also elsewhere on the board
/eeprom/EECLK: U8.11 (SRCLK); also elsewhere on the board
/eeprom/EECS: U8.12 (RCLK); also elsewhere on the board
/eeprom/EEDATA: U8.14 (SER); also elsewhere on the board
/leds_indication/led_indication_0/INDICATION: U8.1 (QB); also elsewhere on the board
/leds_indication/led_indication_0/LED: R17.2; also elsewhere on the board
/leds_indication/led_indication_1/INDICATION: U8.3 (QD); also elsewhere on the board
/leds_indication/led_indication_1/LED: R19.2; also elsewhere on the board
/leds_indication/led_indication_2/INDICATION: U8.5 (QF); also elsewhere on the board
/leds_indication/led_indication_2/LED: R20.2; also elsewhere on the board
/leds_indication/led_indication_3/INDICATION: U8.7 (QH); also elsewhere on the board
/leds_indication/led_indication_3/LED: R21.2; also elsewhere on the board
GND: C26.2, C38.2, C39.2, C40.2, C41.2, C42.2, C43.2, U8.8 (GND); also elsewhere on the board
unnamed: D14.1 (K), J7.1, R17.1
unnamed: D15.1 (K), J7.2, R19.1
unnamed: D16.1 (K), J7.3, R20.1
unnamed: D17.1 (K), J7.4, R21.1

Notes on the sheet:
RX channels

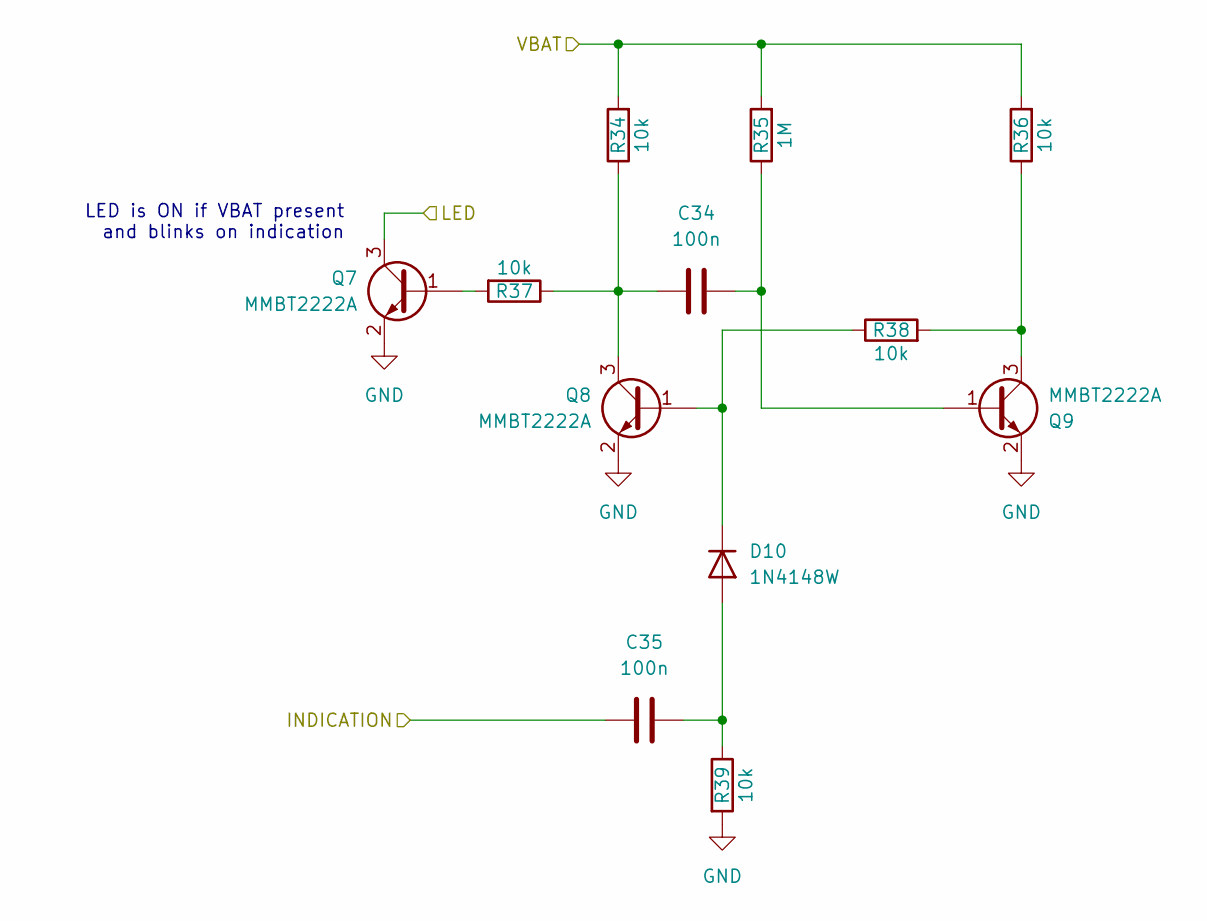
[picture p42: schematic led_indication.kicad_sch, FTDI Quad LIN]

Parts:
C34, C35: 100n; C_0805_2012Metric_Pad1.18x1.45mm_HandSolder
D10: 1N4148W; D_SOD-323_HandSoldering
Q7, Q8, Q9: MMBT2222A; SOT-23
R34, R36, R37, R38, R39: 10k; R_0805_2012Metric
R35: 1M; R_0805_2012Metric

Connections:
/VBAT2: R34.2, R35.2, R36.2; also elsewhere on the board
/leds_indication/led_indication_2/INDICATION: C35.1; also elsewhere on the board
/leds_indication/led_indication_2/LED: Q7.3 (C); also elsewhere on the board
GND: Q7.2 (E), Q8.2 (E), Q9.2 (E), R39.2; also elsewhere on the board
unnamed: C35.2, D10.2 (A), R39.1
unnamed: D10.1 (K), Q8.1 (B), R38.1
unnamed: Q7.1 (B), R37.2
unnamed: C34.1, Q8.3 (C), R34.1, R37.1
unnamed: C34.2, Q9.1 (B), R35.1
unnamed: Q9.3 (C), R36.1, R38.2

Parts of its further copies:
C30, C31, C32, C33, C36, C37: 100n; C_0805_2012Metric_Pad1.18x1.45mm_HandSolder
D11, D12, D13: 1N4148W; D_SOD-323_HandSoldering
Q1, Q2, Q3, Q4, Q5, Q6, Q10, Q11, Q12: MMBT2222A; SOT-23
R22, R24, R25, R26, R27, R28, R30, R31, R32, R33, R40, R42, R43, R44, R45: 10k; R_0805_2012Metric
R23, R29, R41: 1M; R_0805_2012Metric

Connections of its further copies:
/VBAT0: R22.2, R23.2, R24.2; also elsewhere on the board
/VBAT1: R28.2, R29.2, R30.2; also elsewhere on the board
/VBAT3: R40.2, R41.2, R42.2; also elsewhere on the board
/leds_indication/led_indication_0/INDICATION: C31.1; also elsewhere on the board
/leds_indication/led_indication_0/LED: Q1.3 (C); also elsewhere on the board
/leds_indication/led_indication_1/INDICATION: C33.1; also elsewhere on the board
/leds_indication/led_indication_1/LED: Q4.3 (C); also elsewhere on the board
/leds_indication/led_indication_3/INDICATION: C37.1; also elsewhere on the board
/leds_indication/led_indication_3/LED: Q10.3 (C); also elsewhere on the board
GND: Q1.2 (E), Q2.2 (E), Q3.2 (E), Q4.2 (E), Q5.2 (E), Q6.2 (E), Q10.2 (E), Q11.2 (E), Q12.2 (E), R27.2, R33.2, R45.2; also elsewhere on the board
unnamed: C31.2, D11.2 (A), R27.1
unnamed: D11.1 (K), Q2.1 (B), R26.1
unnamed: C33.2, D12.2 (A), R33.1
unnamed: D12.1 (K), Q5.1 (B), R32.1
unnamed: C37.2, D13.2 (A), R45.1
unnamed: D13.1 (K), Q11.1 (B), R44.1
unnamed: Q1.1 (B), R25.2
unnamed: C30.1, Q2.3 (C), R22.1, R25.1
unnamed: C30.2, Q3.1 (B), R23.1
unnamed: Q3.3 (C), R24.1, R26.2
unnamed: Q4.1 (B), R31.2
unnamed: C32.1, Q5.3 (C), R28.1, R31.1
unnamed: C32.2, Q6.1 (B), R29.1
unnamed: Q6.3 (C), R30.1, R32.2
unnamed: Q10.1 (B), R43.2
unnamed: C36.1, Q11.3 (C), R40.1, R43.1
unnamed: C36.2, Q12.1 (B), R41.1
unnamed: Q12.3 (C), R42.1, R44.2

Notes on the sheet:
LED is ON if VBAT present and blinks on indication

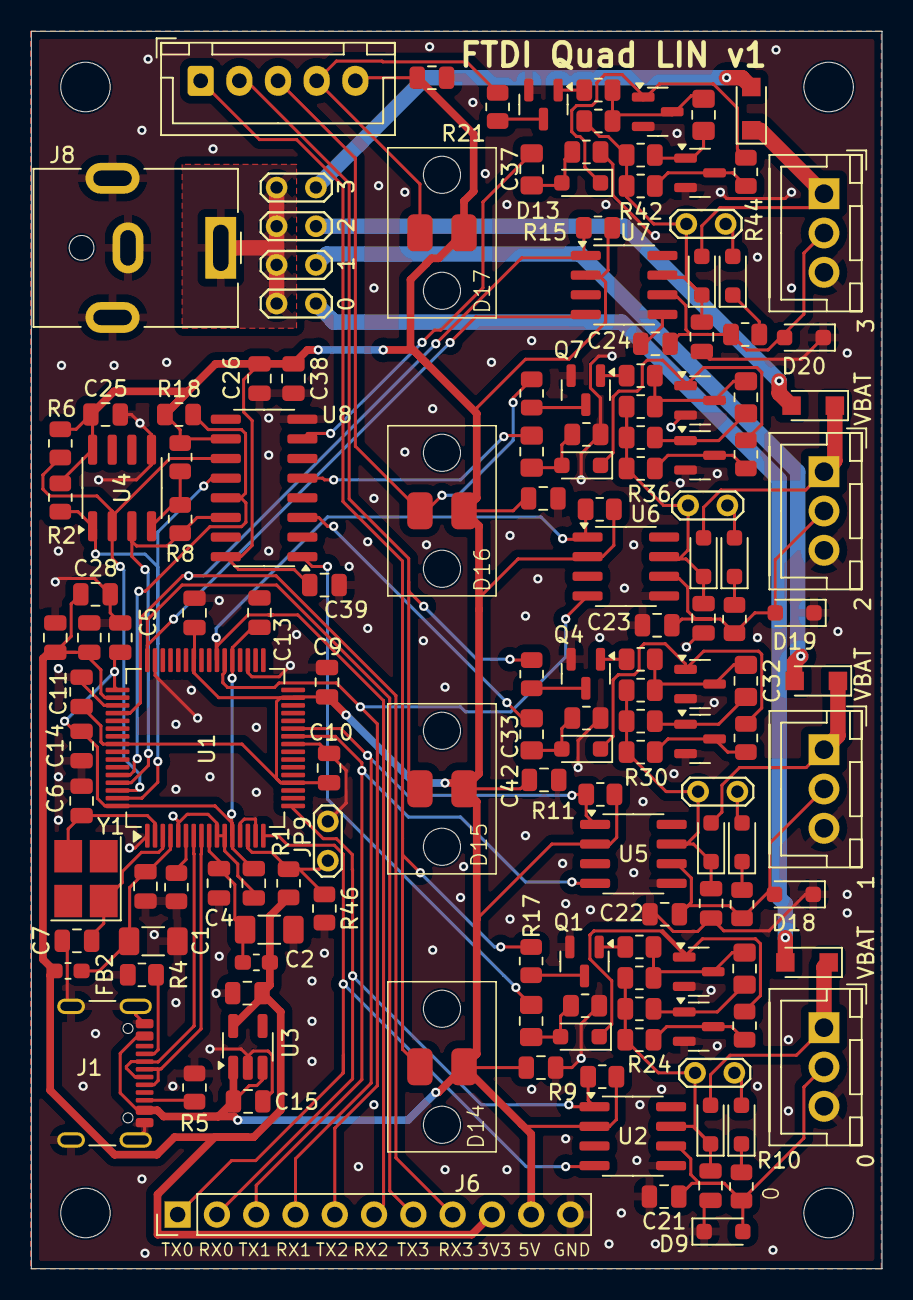
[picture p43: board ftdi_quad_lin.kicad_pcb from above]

Board: 2 copper layers, 55.0 x 80.0 mm, 157 parts (0 on the bottom side), 88 nets.

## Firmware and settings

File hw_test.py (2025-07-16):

import pytest
import os
import can
import select
from plin.device import PLIN, PLINMessage
from plin.enums import PLINMode, PLINMessageType


def read_from_peak(plin: PLIN) -> PLINMessage:
    os.set_blocking(plin.fd, False)

    while True:
        ready, _, _ = select.select([plin.fd], [], [], 1.0)
        if not ready:
            raise TimeoutError("No data received on PLIN fd within 1 second")

        frame = os.read(plin.fd, PLINMessage.buffer_length)
        frame = PLINMessage.from_buffer_copy(frame)
        print(frame)

        if frame.type != PLINMessageType.SLEEP:
            return frame


@pytest.mark.parametrize("chan", [0, 1, 2, 3])
def test_ftdi_sends_to_peak(chan):
    plin = PLIN(interface=f"/dev/plin{chan}")
    plin.start(mode=PLINMode.SLAVE, baudrate=19200)
    plin.set_id_filter(bytearray([0xFF] * 8))

    data = [chan, 0x11, 0x22, 0x33, 0x44, 0x55, 0x66, 0x77]
    frame_id = 0x8

    # Send a master message from FTDI Quad Lin
    with can.Bus(interface="socketcan", channel=f"sllin{chan}") as bus:
        msg = can.Message(arbitration_id=frame_id, data=data, is_extended_id=False)
        bus.send(msg)

    # Read the message from the PLIN device
    frame = read_from_peak(plin)
    print(frame)

    assert frame.id == frame_id
    assert frame.len == len(data)
    assert list(frame.data)[: frame.len] == data

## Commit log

2025-03-14 hw: initial commit
    [eeprom.kicad_sch, ftdi_quad_lin.kicad_pcb, ftdi_quad_lin.kicad_sch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]
2025-03-14 hw: manf for jack
    [ftdi_quad_lin.kicad_pcb, ftdi_quad_lin.kicad_sch, lin.kicad_sch]
2025-03-14 hw: manf for LIN connector
    [lin.kicad_sch]
2025-03-14 hw: manf for USB
    [ftdi_quad_lin.kicad_pcb, ftdi_quad_lin.kicad_sch]
2025-03-14 hw: manf for PMEG4050EP,115
    [ftdi_quad_lin.kicad_pcb, lin.kicad_sch]
2025-03-14 hw: BOM settings
2025-03-14 hw: led RC changed 220n->100n
    [ftdi_quad_lin.kicad_pcb, led_indication.kicad_sch]
2025-03-14 hw: added pdf schematics
2025-06-02 initial case
    [LED3mm_bezel.stl, LED3mm_bezel_retainer.stl, bom.csv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]
2025-07-16 README.md: added case photo
